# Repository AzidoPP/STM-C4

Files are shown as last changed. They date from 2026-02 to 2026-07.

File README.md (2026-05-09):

# STM-C4
A CS2 C4 model based on STM32.





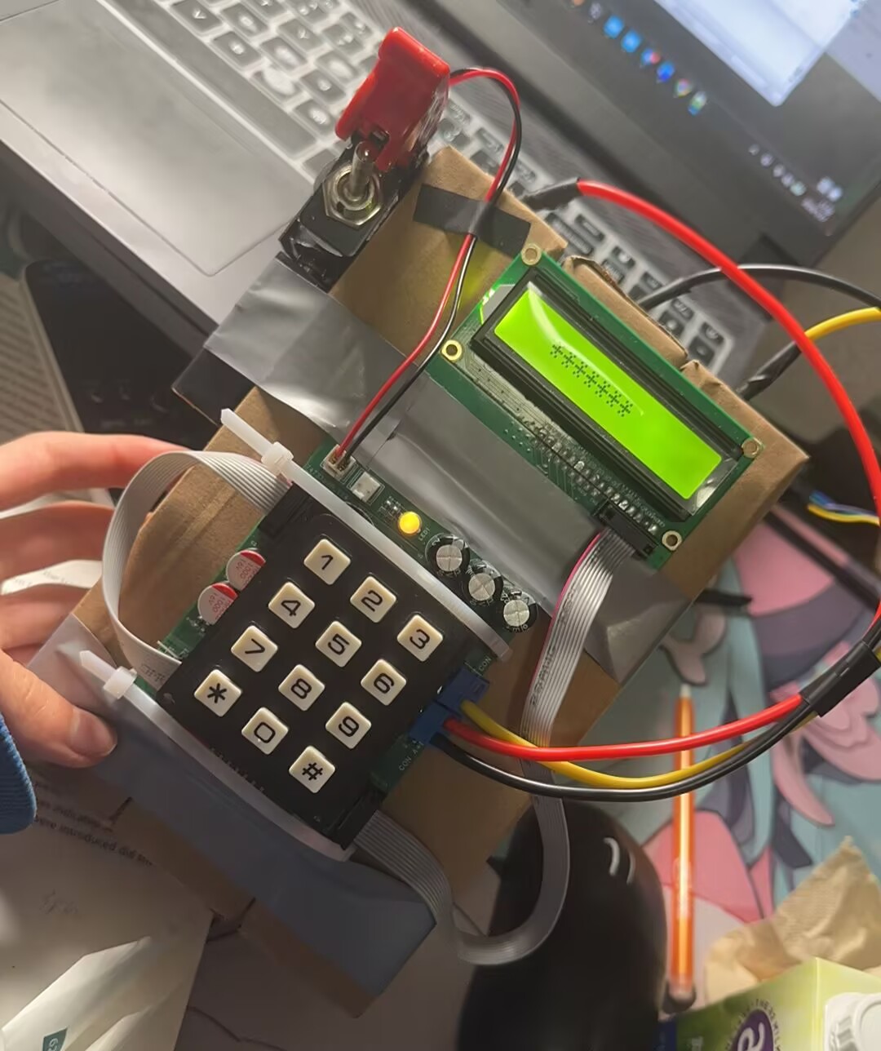
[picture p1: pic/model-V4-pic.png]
model-v4-pic


## 简介
- 基于 STM32F103C8T6 的 CS2 C4 外观模型，主要用于学习、展示与收藏。
- 开发环境：Keil5 + ST-Link，外部 8 MHz 晶振。
- 快速开始: **[Ver4.0](Ver4.0)**。
- 配置修改请参考：[`Ver4.0/CONFIG.md`](Ver4.0/CONFIG.md)

## 特别感谢
- 感谢 Bilibili 博主「下界石嘤」提供 3D 打印模型：[https://space.bilibili.com/318570767](https://space.bilibili.com/318570767)

[English](#english)

## 免责声明
本项目为外观复刻模型，不具备任何真实功能或危险性。
任何改装、滥用或非法使用均与原作者无关，原作者不承担由此产生的责任。

## English
- A CS2 C4 appearance model based on STM32F103C8T6, for learning, demos, and collection.
- Tooling: Keil5 + ST-Link with an external 8 MHz HSE.
- Quick start: **[Ver4.0](Ver4.0)**
- For configuration edits, see [`Ver4.0/CONFIG.md`](Ver4.0/CONFIG.md).

## Special Thanks
- Thanks to Bilibili creator “下界石嘤” for providing the 3D printable models: [https://space.bilibili.com/318570767](https://space.bilibili.com/318570767)

## Disclaimer
This project is a replica appearance model and has no real functionality or hazardous capability.
Any modification, misuse, or illegal use is not associated with the original creator, who assumes no responsibility for any consequences.

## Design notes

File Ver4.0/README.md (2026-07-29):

# STM-C4 Ver4.0

<div align="right">
  <strong>English</strong> | <a href="README_zh.md">简体中文</a>
</div>






An STM32F103C8T6-based CS2 C4 appearance model (V4.0). About 95% visual accuracy. Compared to the previous version, this revision optimizes the LCD ribbon width, uses multi-color LEDs, adds a passive buzzer for distinct tones, and introduces an external defuser option. The hardware integrates the power circuit and uses a PCB-mounted controller instead of a full dev board. On the software side, the countdown uses a more accurate formula, smoother animations, and more configurable options with a more authentic LCD effect.

GitHub repo (firmware/docs): https://github.com/AzidoPP/STM-C4  
OSHWHUB hardware page: https://oshwhub.com/azidopp/CS2-C4

### Real Picture



### Quick Start

1. PCB fabrication
   - Main board Gerber: [PCB_Gerber/Gerber_C4_MainBoardV4.1.zip](PCB_Gerber/Gerber_C4_MainBoardV4.1.zip)
   - LCD adapter Gerber: [PCB_Gerber/Gerber_LCD1601_AdapterBoardV4.0.zip](PCB_Gerber/Gerber_LCD1601_AdapterBoardV4.0.zip)
   - EasyEDA original project files (this repo): [EasyEDA_proj](EasyEDA_proj/)
   - See OSHWHUB for the full hardware [project files](https://oshwhub.com/azidopp/CS2-C4)
2. BOM purchase
   - BOM file: [BOM/BOM.xlsx](BOM/BOM.xlsx)
   - 9V alkaline batteries are recommended for more stable current output
3. Soldering & assembly
   - LCD1601 adapter soldering example:
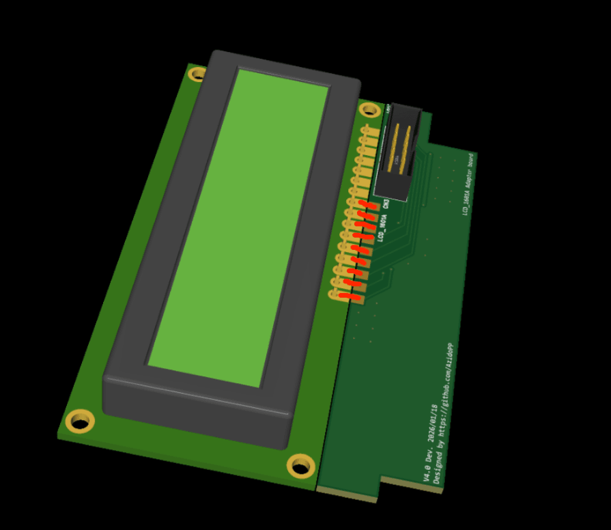
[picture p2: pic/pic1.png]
LCD1601 adapter pic1
     
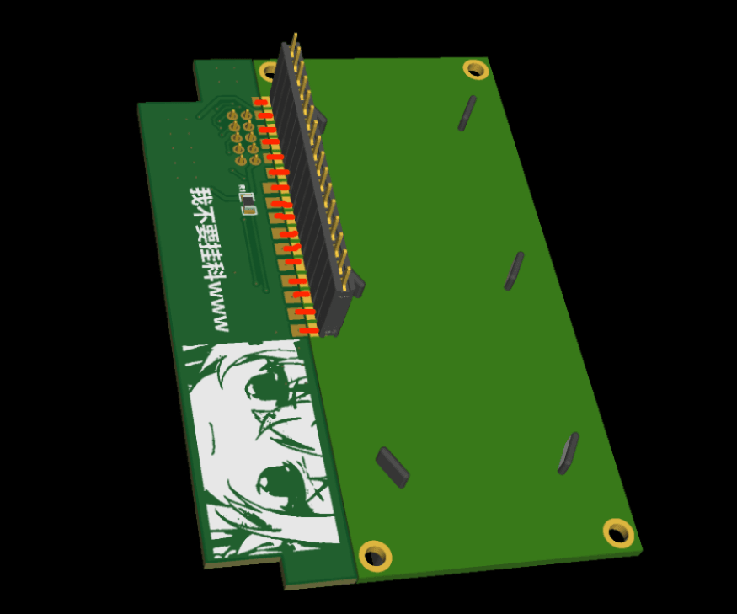
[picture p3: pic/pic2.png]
LCD1601 adapter pic2
     
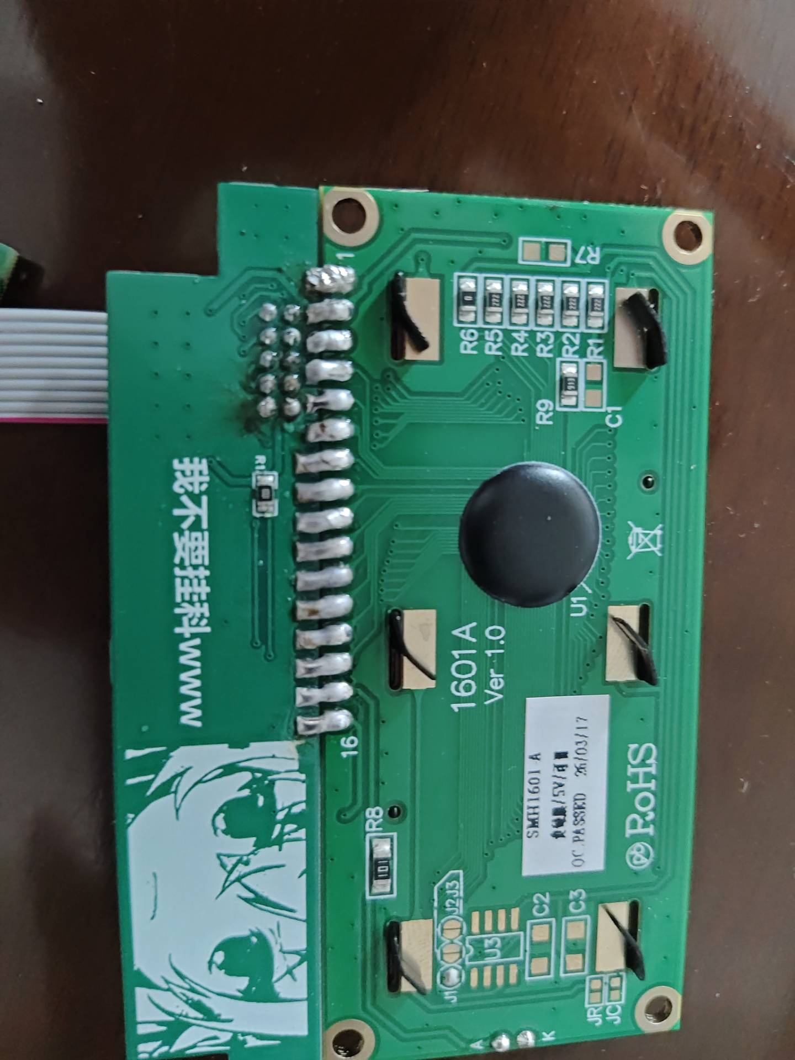
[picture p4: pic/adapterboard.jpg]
LCD1601 adapter pic3
     
   - 3D printed shell/fillers (optional): see [3DP_Models](3DP_Models/)
   - Fully assembled board:
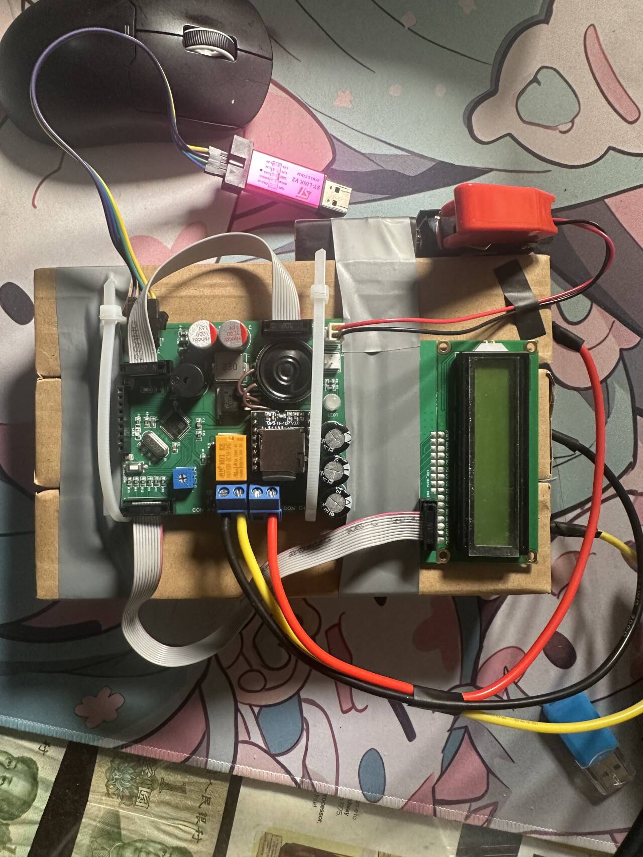
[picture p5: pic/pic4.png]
Full assambled board
     
4. Flash firmware
   - Keil project: [Keil_proj/c4](Keil_proj/c4/)
   - ST-Link V2 header location:
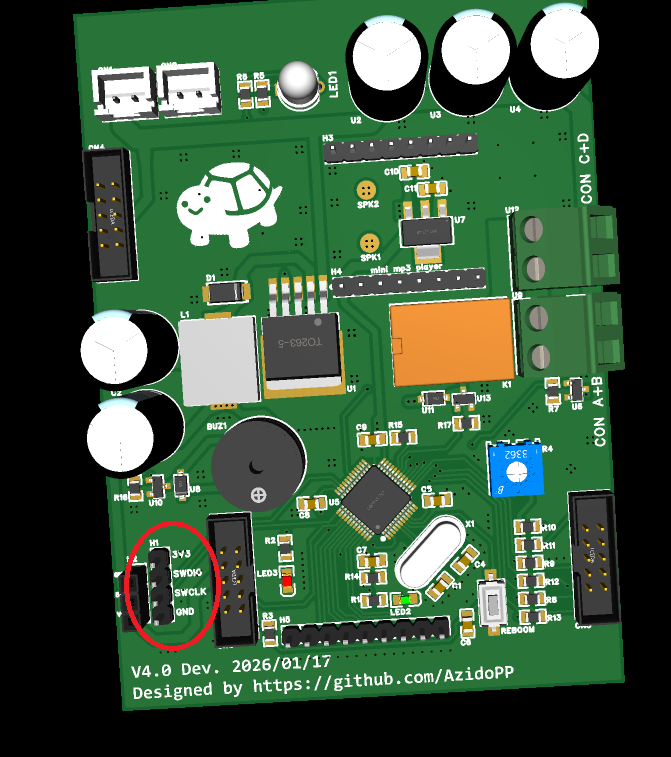
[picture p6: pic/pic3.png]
ST-Link header pic3
     
   - Pin order: 3.3V / SWDIO / SWCLK / GND
   - After flashing the firmware, if the LCD1601 shows no text, rotate the potentiometer in either direction to adjust the display contrast until the text is clear.
     potentiometer
5. MP3 audio (optional)
   - Copy [TFCard_Files/](TFCard_Files/) contents to the TF card root
   - Details: [TFCard_Files](TFCard_Files/)
6. Configuration and tuning
   - User guide: [`CONFIG.md`](CONFIG.md)
   - Default configuration source: [`config.h`](Keil_proj/c4/user/config.h)
   - Supports single-item configuration update without reflashing (hold `#` during power-on)
   - Added digital countdown toggle: `CONFIG_DIGITAL_COUNTDOWN_ENABLE`

### Basic Gameplay

- Startup uses buzzer only (no MP3), while LED breathes in yellow.
- Enter any 7-digit code as the “plant” password.
- After entry, the countdown starts (default 40s, configurable); the LED and buzzer become more urgent.
- During the countdown, there are three defuse methods:
  - Password defuse: enter the same password again to defuse successfully.
  - Manual defuse: long press `#` to start; succeed after 10 seconds.
  - External defuser: when the external defuse input is active, hold for 5 seconds to succeed.
- Defuse-success sequence: defuse-success cue (separate toggle) -> (optional) CT music box -> (optional) CT win announcement.
- Explosion sequence:
  - With T music box enabled: play integrated explosion+music-box track -> (optional) T win announcement.
  - Without T music box: play pure explosion track -> (optional) T win announcement.

### Configuration

- User-facing configuration guide: [`CONFIG.md`](CONFIG.md)
- Technical notes: [`V4说明.md`](V4说明.md)
- Default configuration source: [`config.h`](Keil_proj/c4/user/config.h)

### Detailed Docs

For deeper details and theory, see the Chinese technical document: [V4说明.md](V4说明.md)

### Disclaimer

This project is a visual/electronic replica and does not have any real functionality or danger.  
Any modification, misuse, or illegal use is not associated with the author, and the author assumes no liability.

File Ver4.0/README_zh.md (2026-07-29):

# STM-C4 Ver4.0

<div align="right">
  <a href="README.md">English</a> | <strong>简体中文</strong>
</div>






基于 STM32F103C8T6 的 CS2 C4 光电模型，第 4 版。还原度约 95%，相较于先前版本，优化了显示屏排线宽度，使用多色 LED，使用无源蜂鸣器（可以发出不同音调），添加了“拆弹器”支持。硬件方面使用了集成的电源电路，以及集成在 PCB 上的控制器取代原先的整个开发板。软件方面改进：倒计时使用了更还原的公式，修改了更好的动画，添加了更多可配置选项，使用了更还原的显示屏动画。

GitHub 仓库（程序/文档）：https://github.com/AzidoPP/STM-C4  
OSHWHUB 硬件开源地址：https://oshwhub.com/azidopp/CS2-C4

### 实物图



### 快速开始

1. PCB 打样
   - 主板 Gerber：[PCB_Gerber/Gerber_C4_MainBoardV4.1.zip](PCB_Gerber/Gerber_C4_MainBoardV4.1.zip)
   - LCD 转接板 Gerber：[PCB_Gerber/Gerber_LCD1601_AdapterBoardV4.0.zip](PCB_Gerber/Gerber_LCD1601_AdapterBoardV4.0.zip)
   - 立创 EDA 原始工程文件（本仓库）：[EasyEDA_proj](EasyEDA_proj/)
   - 详细工程请参考 OSHWHUB 开源硬件平台[工程](https://oshwhub.com/azidopp/CS2-C4)
2. 采购 BOM
   - BOM 文件：[BOM/BOM.xlsx](BOM/BOM.xlsx)
   - 9V 电池建议使用碱性电池（输出电流更稳定）
3. 焊接与装配
   - LCD1601 转接板焊接示例：
     LCD1601 adapter pic1
     LCD1601 adapter pic2
     LCD1601 adapter pic3
   - 3D 打印外壳/填充件（可选）：见 [3DP_Models](3DP_Models/)
   - 完整组装：
     Full assambled board
4. 烧录固件
   - Keil 工程：[Keil_proj/c4](Keil_proj/c4/)
   - ST-Link V2 接口位置：
     ST-Link header pic3
   - 引脚顺序：3.3V / SWDIO / SWCLK / GND
   - 烧录固件后，如果 LCD1601 显示屏不显示，请旋转电位器调整屏幕对比度，左右旋转，直到出现清晰的文字。
     potentiometer
5. MP3 音效（可选）
   - 将 [TFCard_Files/](TFCard_Files/) 内容复制到 TF 卡根目录
   - 详细说明见：[TFCard_Files](TFCard_Files/)
6. 配置与修改
   - 用户配置说明：[`CONFIG.md`](CONFIG.md)
   - 默认配置定义文件：[`Keil_proj/c4/user/config.h`](Keil_proj/c4/user/config.h)
   - 可在不重新烧录的情况下修改单个配置（上电时按住 `#` 进入配置模式）
   - 新增倒计时数字显示开关：`CONFIG_DIGITAL_COUNTDOWN_ENABLE`

### 基础玩法

- 上电阶段仅蜂鸣器提示（不播放 MP3），LED 为黄色呼吸灯模式。
- 输入任意 7 位密码，作为“下包密码”。
- 输入完成后进入倒计时（默认 40 秒，可配置），期间 LED 和蜂鸣器会逐渐急迫。
- 倒计时期间有三种拆弹方式：
  - 输入拆弹：再次输入与下包一致的密码即可拆弹成功。
  - 手动拆弹：长按 `#` 开始拆弹，持续 10 秒后成功。
  - 外部拆弹器：外部拆弹输入有效时开始拆弹，持续 5 秒即成功。
- 拆弹成功播放序列：拆弹成功音（可单独开关）->（可选）CT 音乐盒 ->（可选）CT 胜利播报。
- 倒计时结束未拆弹播放序列：
  - 启用 T 音乐盒：播放“爆炸+T 音乐盒”整合音频 ->（可选）T 胜利播报。
  - 未启用 T 音乐盒：播放纯爆炸音效 ->（可选）T 胜利播报。

### 配置

- 用户配置指南（含编号与操作步骤）：[`CONFIG.md`](CONFIG.md)
- 默认配置定义文件：[`Keil_proj/c4/user/config.h`](Keil_proj/c4/user/config.h)
- 技术说明：[`V4说明.md`](V4说明.md)

### 详细说明

更多细节与原理说明请查看：[V4说明.md](V4说明.md)

### 免责声明

本项目为外观光电复刻模型，不具备任何真实功能或危险性。  
任何改装、滥用或非法使用与原作者无关，原作者不承担责任。

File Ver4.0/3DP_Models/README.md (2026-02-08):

# 3D 打印说明

## 中文
- `C4_filler` 为填充件，请务必打印。
- 单个填充件尺寸约 190 x 40 x 43 mm（长 x 宽 x 高），以模型文件为准。
- 整体外壳尺寸约 190 x 123 mm（长 x 宽），以模型文件为准。
- 建议填充率 7%~15%，普通材料即可，性价比高。
- 没有打印机可找本地 3D 打印代工，或联系模型提供者 UP 主获取打印件（见下方链接）。
- 不建议选择超低价平台，容易踩坑。
- 总开关外壳文件：`switch_shell`，推荐黑色。

模型来源：
- Bilibili 博主「下界石嘤」提供
- 链接：[https://space.bilibili.com/318570767](https://space.bilibili.com/318570767)

---

## English
- `C4_filler` is the filler part and must be printed.
- Filler size is about 190 x 40 x 43 mm (L x W x H). Refer to the model files for exact dimensions.
- Overall shell size is about 190 x 123 mm (L x W). Refer to the model files for exact dimensions.
- Recommended infill: 7%–15%. Standard materials are fine and cost-effective.
- If you don't have a printer, use a local 3D printing service or contact the model provider (see the link below) for printed parts.
- Avoid ultra-cheap platforms; the quality and pricing are often unreliable.
- Main switch shell file: `switch_shell`, black color recommended.

Model credit:
- Provided by Bilibili creator “下界石嘤”
- Link: [https://space.bilibili.com/318570767](https://space.bilibili.com/318570767)

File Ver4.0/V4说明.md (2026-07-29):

# STM-C4 Ver4.0 说明

主控 STM32F103C8T6，外部 8MHz 高速晶振，使用 Keil5 + ST-Link。

A CSGO game C4 bomb model based on STM32.

## 1. LCD1601A
- 默认倒装安装（`CONFIG_LCD_NORMAL_MOUNT = 0`），正装可设为 `1`。
- 倒装时显示从右往左，字符需整体旋转 180 度；正装时按正常方向显示。
  - 例如用户看到左对齐的 `ABCDEF`，倒装实际需要显示右对齐的 `FEDCBA` 并旋转字符。
- 字符集：实际只需要 `0123456789*`（驱动内置 CGRAM 字库）。
- 采用 4 线模式。

引脚定义（硬件连接）：
- RS: PB12
- EN: PB14
- D4 ~ D7: PA4 ~ PA7
- 背光：PA3（高电平点亮，推挽，PWM 控制，亮度 `CONFIG_LCD_BACKLIGHT_PCT`）

电平/驱动：
- LCD1601A 使用 5V 电平，外部上拉到 5V。
- 信号脚使用开漏输出（OD）。

实现要点（简化说明）：
- 初始化流程与 HD44780 类似：上电延时、写入 0x03/0x02、功能设置、清屏、显示开等。
- 通过自定义 CGRAM 字库加载字符；显示方向与列映射由驱动根据 `CONFIG_LCD_NORMAL_MOUNT` 处理。
- 字体按 7x5 顶部对齐显示（底部 1 行留空），避免底部贴边。
- 参考实现见：`Ver4.0/Keil_proj/c4/hardware/1601a.c`

## 2. 矩阵键盘
- 引脚：PB15 PB4 PB5 PB6 PB7 PB8 PB9
- 排列：

```
        PB5     PB15    PB7
PB4     [1]     [2]     [3]
PB9     [4]     [5]     [6]
PB8     [7]     [8]     [9]
PB6     [*]     [0]     [#]
```

## 3. 蜂鸣器
- 无源蜂鸣器（含驱动电路，MOS 管，栅极 10k 下拉）。
- 栅极连接 PB0。
- PB0 输出 PWM 波驱动。
- 原版CS2中，A区下包后倒计时音频为4250Hz，B区下包倒计时为3600Hz

## 4. LED
- PC13：系统指示 LED（一般不用，仅调试，推挽高电平点亮）。
- 用户双色 LED（推挽高电平点亮）：
  - PA2 红
  - PA1 绿
- 黄色由红绿同时点亮并用 PWM 调节比例，比例由 `CONFIG_LED_YELLOW_RED_PCT` 控制。
  - 例如 `CONFIG_LED_YELLOW_RED_PCT = 70` 表示红色约 70%、绿色 100%。

## 5. 继电器
- 已包含 MOS + 续流驱动。
- PB1 高电平：继电器吸合。
- 倒计时结束后“引爆”吸合继电器
- 端口`C`为继电器常开脚，端口`D`为继电器常闭脚。吸合后`C`脚成为GND，可以与`A`脚（VCC）产生9V电压。

## 6. MP3 模块
- PA9 串口（USART1 TX），用于播放 C4 模型音效/音乐盒。
- MP3 命令封装参考：`Ver4.0/Keil_proj/c4/hardware/Serial.c` 与 `mp3.c`。
- 主逻辑采用 `MP3Sequence` 状态机（`main.c`），所有流程音频统一由状态机调度。
- 播放方式：按文件名播放，音频统一放在 TF 卡根目录 `MP3/` 文件夹。
- 固定播报编号：
  - 下包成功：`CONFIG_MP3_TRACK_ARM_SUCCESS`（默认 0101）
  - 纯爆炸：`CONFIG_MP3_TRACK_EXPLOSION`（默认 0102）
  - 拆弹成功：`CONFIG_MP3_TRACK_DEFUSE_SUCCESS`（默认 0103）
  - CT 胜利播报：`CONFIG_MP3_TRACK_CTWIN`（默认 0104）
  - T 胜利播报：`CONFIG_MP3_TRACK_TERWIN`（默认 0105）
- 音乐盒编号由配置控制：`CONFIG_MP3_CT_WIN_MUSICBOX_TRACK` / `CONFIG_MP3_T_WIN_MUSICBOX_TRACK`。

详细映射见：`TFCard_Files/README.md`

## 7. 外部“拆弹器”
- PB3 上拉输入，低电平有效。
- PB3 外部持续下拉达到 `CONFIG_EXTERNAL_DEFUSE_MS` 即判定拆弹成功（默认 5000ms）。

## 流程（完整）
1. LED 黄色呼吸灯模式（`CONFIG_LED_BREATH_PERIOD_MS`）。
2. 上电音频：仅蜂鸣器（`CONFIG_STARTUP_BEEP_ENABLE` / `CONFIG_STARTUP_BEEP_ON_MS` / `CONFIG_STARTUP_BEEP_GAP_MS`），不播放 MP3。
3. 倒计时蜂鸣器频率：`CONFIG_BUZZER_COUNTDOWN_FREQ_HZ`。
4. 等待输入密码（长度 `CONFIG_PASSWORD_LEN`）。未输入时显示全 `+`；输入第一位后，未填位改为 `-`，数字从右向左累积。输入完成后延迟 `CONFIG_ARM_DELAY_MS` 再进入倒计时，避免误触。
5. 记录该密码（输入期间 LED 仍为呼吸灯）。
6. 进入倒计时（总时长 `CONFIG_COUNTDOWN_MS`）：
   - 蜂鸣节奏由 `CONFIG_BEEP_LEN_MS` 与 `CONFIG_BEEP_INTERVAL_*` 控制
   - 每次蜂鸣时 LED 红色，非蜂鸣时 LED 熄灭

## 倒计时蜂鸣模式
原 CS:GO C4 蜂鸣公式如下（BPS = Beeps Per Second）：

```
f(t) = 1.05 · exp(0.0054t + 0.000871t²)
```
- t：时间（秒），0 ≤ t ≤ 45

更通用的比例形式：
```
g(p) = 1.049 · exp(0.244p + 1.764p²)
```
- p：已过去时间比例，0.0 ≤ p ≤ 1.0

蜂鸣长度固定为 125ms。

频率：
```
freq = MAX(0.1 + 0.9 * fComplete, 0.15)
```
- fComplete 为剩余时间比例（40/40 到 0/40）
- 下包后设置下一次蜂鸣时间：`gpGlobals->curtime + 1.0`

倒计时时显示 `+++` 往返滚动；默认关闭数字倒计时，此时动画覆盖整行。开启数字倒计时后，`+++` 仅在左半区滚动，右半区显示 `mm:ss`。

注意：LCD1601A 是倒装的，所以符号位置与显示方向需整体翻转 180°。

## 倒计时拆弹（3 种方式，且必须非阻塞）
> 拆弹失败或进行中都不应影响倒计时精度。旧版本因键盘扫描 + 倒计时循环阻塞，长按按键会导致消抖延时叠加、倒计时不准。V4.0 采用时间基准 + 状态机避免此问题。

1. **输入密码拆弹**：输入与下包相同密码即成功（`CONFIG_DEFUSE_ENABLE_PASSWORD`）。
2. **长按 # 手动拆弹**：长按超过 `CONFIG_LONG_PRESS_MS` 后开始拆弹，持续 `CONFIG_MANUAL_DEFUSE_MS` 即成功（`CONFIG_DEFUSE_ENABLE_MANUAL`）。
   - 过程显示：右端数字按 `CONFIG_DEFUSE_CYCLE_STEPS` 滚动，已确认的正确密码逐位向左累积；其余位以 `+` 和 `-` 交替闪烁。
3. **外部拆弹器拆弹**：PB3 触发后开始拆弹，持续 `CONFIG_EXTERNAL_DEFUSE_MS` 即成功（`CONFIG_DEFUSE_ENABLE_EXTERNAL`）。

拆弹成功后，LCD 按 `+++++++` → `-------` → 正确密码循环显示，每帧间隔由 `CONFIG_DEFUSE_BLINK_MS` 控制。

拆弹成功会进入 DEFUSE 音频序列：
- 若启用 `CONFIG_MP3_DEFUSE_STAGE_ENABLE`：
  - 若启用 `CONFIG_MP3_DEFUSE_SUCCESS_ENABLE`，播放 `CONFIG_MP3_TRACK_DEFUSE_SUCCESS` 并等待 `CONFIG_MP3_DEFUSE_SUCCESS_WAIT_MS`
  - 若启用 `CONFIG_MP3_CT_WIN_MUSICBOX_ENABLE`，播放 `CONFIG_MP3_CT_WIN_MUSICBOX_TRACK` 并等待 `CONFIG_MP3_CT_MUSICBOX_WAIT_MS`
  - 若启用 `CONFIG_MP3_CTWIN_ENABLE`，播放 `CONFIG_MP3_TRACK_CTWIN`

## 爆炸行为
- 倒计时结束未拆弹：继电器吸合。
- 播放 EXPLOSION 序列（按配置可启停各阶段）：
  - 若启用 `CONFIG_MP3_EXPLODED_STAGE_ENABLE` 且启用 `CONFIG_MP3_EXPLOSION_ENABLE`：
    - 启用 `CONFIG_MP3_T_WIN_MUSICBOX_ENABLE`：播放 T 音乐盒并等待 `CONFIG_MP3_T_MUSICBOX_WAIT_MS`
    - 未启用 T 音乐盒：播放纯爆炸音效并等待 `CONFIG_MP3_EXPLOSION_ONLY_WAIT_MS`
  - 若启用 `CONFIG_MP3_TERWIN_ENABLE`，播放 `CONFIG_MP3_TRACK_TERWIN`
- LED 输出 100% 黄色（LED 与音乐盒同时）。

## 软件架构（文件职责）
- `Ver4.0/Keil_proj/c4/user/main.c`
  - 应用状态机与主循环（Idle/Countdown/Success/Exploded）
  - 倒计时逻辑、拆弹流程、输入处理
- `Ver4.0/Keil_proj/c4/sys/Systick.c`
  - 1ms 时间基准（TIM4 中断）
- `Ver4.0/Keil_proj/c4/user/stm32f10x_it.c`
  - TIM4 中断处理，驱动时间基准
- `Ver4.0/Keil_proj/c4/hardware/MatrixKey.c`
  - 矩阵键盘扫描与消抖
- `Ver4.0/Keil_proj/c4/hardware/1601a.c`
  - LCD1601A 驱动（倒装/正装显示、CGRAM 字库、背光 PWM）
- `Ver4.0/Keil_proj/c4/hardware/LED.c`
  - 红/绿 LED PWM、黄色配比、继电器控制
  - 蜂鸣器 PWM 频率与占空比控制
- `Ver4.0/Keil_proj/c4/hardware/Serial.c`
  - USART1 发送封装（供 MP3 模块使用）
- `Ver4.0/Keil_proj/c4/hardware/mp3.c`
  - MP3 指令封装
- `Ver4.0/Keil_proj/c4/sys/Delay.c`
  - 短时硬件延时（LCD 时序/少量效果）
- `Ver4.0/Keil_proj/c4/user/config.h`
  - 功能开关与参数配置
- `Ver4.0/Keil_proj/c4/user/config_range.h`
  - 配置范围检查

## 配置入口
配置集中在 `Ver4.0/Keil_proj/c4/user/config.h`，用户说明在 `Ver4.0/config.md`。

新增运行时配置管理：
- `Ver4.0/Keil_proj/c4/user/config_manager.c`
- `Ver4.0/Keil_proj/c4/user/config_manager.h`

运行时配置机制要点：
- 程序启动时读取配置记录；若记录无效/版本不匹配/配置项数量不匹配，则回退到固件内默认值。
- 配置结构附带 magic / version / count / checksum，用于兼容新增配置项。
- 重新烧录后若配置结构变化，旧记录不会被继续使用。
- Keil + ST-Link 下载通常会擦除目标程序相关区域；是否整片擦除取决于下载配置，不保证每次整片擦除。

配置模式流程（上电按住 `#`）：
- 进入条件：上电/复位后的极短检测窗口内检测到已按住 `#`，并继续按住一小段时间后进入。
- 操作：输入配置编号 -> 输入新值 -> 保存确认。
- 特殊输入码：`090405`（固定 6 位）进入恢复默认确认流程。
- 保存或恢复成功后，停留提示并等待用户 `RESET`。

显示约束处理：
- LCD 仅 16 字符，配置模式统一使用短提示（如 `ID:` / `VAL:` / `SAVE?` / `RESET`）。
- 避免提示过长导致可读性下降。

倒计时显示新增：
- 新增 `CONFIG_DIGITAL_COUNTDOWN_ENABLE`。
- 开启后：左侧保持滚动动画，右侧 8 字符区域显示 `mm:ss`（前置 2 个空格）。
- 进入拆弹动画时自动隐藏数字倒计时，仅显示拆弹动画。

常用配置（宏）：
- 密码与上电：`CONFIG_PASSWORD_LEN` / `CONFIG_PASSWORD_COL` / `CONFIG_ARM_DELAY_MS` / `CONFIG_ARM_PRESET_ENABLE` / `CONFIG_ARM_PRESET_PASSWORD`
- 倒计时与滚动：`CONFIG_COUNTDOWN_MS` / `CONFIG_SCROLL_INTERVAL_MS` / `CONFIG_SCROLL_PATTERN_LEN`（预留，当前实现固定三个加号）
- 蜂鸣器节奏：`CONFIG_BEEP_LEN_MS` / `CONFIG_BEEP_INTERVAL_BASE_MS` / `CONFIG_BEEP_INTERVAL_SCALE_MS` / `CONFIG_BEEP_INTERVAL_MIN_MS` / `CONFIG_BEEP_INITIAL_MS`
- 蜂鸣器频率：`CONFIG_BUZZER_STARTUP_FREQ_HZ` / `CONFIG_BUZZER_COUNTDOWN_FREQ_HZ` / `CONFIG_BUZZER_DUTY_PCT`
- 拆弹设置：`CONFIG_DEFUSE_ENABLE_PASSWORD` / `CONFIG_DEFUSE_ENABLE_MANUAL` / `CONFIG_DEFUSE_ENABLE_EXTERNAL`
- 拆弹时间与过程：`CONFIG_LONG_PRESS_MS` / `CONFIG_MANUAL_DEFUSE_MS` / `CONFIG_EXTERNAL_DEFUSE_MS` / `CONFIG_DEFUSE_CYCLE_STEPS` / `CONFIG_DEFUSE_DISPLAY_HOLD_MS`
- 拆弹成功显示：`CONFIG_DEFUSE_BLINK_MS`（当前生效）/ `CONFIG_DEFUSE_FLASH_TOGGLE_MS` / `CONFIG_DEFUSE_FLASH_TOGGLES`（预留）
- LCD/LED：`CONFIG_LCD_COLS` / `CONFIG_LCD_BACKLIGHT_PCT` / `CONFIG_LCD_NORMAL_MOUNT` / `CONFIG_LED_PWM_MAX` / `CONFIG_LED_BREATH_PERIOD_MS` / `CONFIG_LED_YELLOW_RED_PCT`
- MP3：
  - 基础：`CONFIG_MP3_VOLUME` / `CONFIG_MP3_ARM_SUCCESS_ENABLE`
  - 固定播报号：`CONFIG_MP3_TRACK_ARM_SUCCESS` / `CONFIG_MP3_TRACK_EXPLOSION` / `CONFIG_MP3_TRACK_DEFUSE_SUCCESS` / `CONFIG_MP3_TRACK_CTWIN` / `CONFIG_MP3_TRACK_TERWIN`
  - 阶段总开关：`CONFIG_MP3_DEFUSE_STAGE_ENABLE` / `CONFIG_MP3_EXPLODED_STAGE_ENABLE`
  - 子开关：`CONFIG_MP3_DEFUSE_SUCCESS_ENABLE` / `CONFIG_MP3_EXPLOSION_ENABLE` / `CONFIG_MP3_CT_WIN_MUSICBOX_ENABLE` / `CONFIG_MP3_T_WIN_MUSICBOX_ENABLE` / `CONFIG_MP3_CTWIN_ENABLE` / `CONFIG_MP3_TERWIN_ENABLE`
  - 音乐盒编号：`CONFIG_MP3_CT_WIN_MUSICBOX_TRACK` / `CONFIG_MP3_T_WIN_MUSICBOX_TRACK`
  - 等待时长：`CONFIG_MP3_DEFUSE_SUCCESS_WAIT_MS` / `CONFIG_MP3_CT_MUSICBOX_WAIT_MS` / `CONFIG_MP3_T_MUSICBOX_WAIT_MS` / `CONFIG_MP3_EXPLOSION_ONLY_WAIT_MS`

## 工程与编译
Keil 工程文件：`Ver4.0/Keil_proj/c4/Project.uvprojx`

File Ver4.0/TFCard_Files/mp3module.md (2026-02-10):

Copy your mp3 into you micro SD card

NOTE: The order you copy the mp3 into micro SD card will affect the order mp3 played , which means play(1) function will play the first mp3 copied into micro SD card.

For Mac User

NOTE: If you are using Mac OS X to copy the mp3, the file system will automatically add hidden files like: ".\_0001.mp3" for index, which this module will handle as valid mp3 files. It is really annoying. So you can run following command in terminal to eliminate those files.

dot\_clean /Volumes/<SDVolumeName>

Please replace the to the volume name of your SD card.

Sample Code

We've created an Arduino library for DFPlayer Mini to simplify the method for you to make it work.

Connect the hardware as the picture above shown and play with the sample code.

You can download the latest library here: DFRobotDFPlayerMini.

Sample code "GetStarted", switching to next song every 3 seconds

/\*\*\*\*\*\*\*\*\*\*\*\*\*\*\*\*\*\*\*\*\*\*\*\*\*\*\*\*\*\*\*\*\*\*\*\*\*\*\*\*\*\*\*\*\*\*\*\*\*\*\*

DFPlayer - A Mini MP3 Player For Arduino

&nbsp;<https://www.dfrobot.com/product-1121.html>

&nbsp;

&nbsp;\*\*\*\*\*\*\*\*\*\*\*\*\*\*\*\*\*\*\*\*\*\*\*\*\*\*\*\*\*\*\*\*\*\*\*\*\*\*\*\*\*\*\*\*\*\*\*\*\*\*\*

&nbsp;This example shows the basic function of library for DFPlayer.

&nbsp;

&nbsp;Created 2016-12-07

&nbsp;By \[Angelo qiao](Angelo.qiao@dfrobot.com)

&nbsp;

&nbsp;GNU Lesser General Public License.

&nbsp;See <http://www.gnu.org/licenses/> for details.

&nbsp;All above must be included in any redistribution

&nbsp;\*\*\*\*\*\*\*\*\*\*\*\*\*\*\*\*\*\*\*\*\*\*\*\*\*\*\*\*\*\*\*\*\*\*\*\*\*\*\*\*\*\*\*\*\*\*\*\*\*\*\*\*/

/\*\*\*\*\*\*\*\*\*\*\*Notice and Trouble shooting\*\*\*\*\*\*\*\*\*\*\*\*\*\*\*

&nbsp;1.Connection and Diagram can be found here

&nbsp;<https://www.dfrobot.com/wiki/index.php/DFPlayer\_Mini\_SKU:DFR0299#Connection\_Diagram>

&nbsp;2.This code is tested on Arduino Uno, Leonardo, Mega boards.

&nbsp;\*\*\*\*\*\*\*\*\*\*\*\*\*\*\*\*\*\*\*\*\*\*\*\*\*\*\*\*\*\*\*\*\*\*\*\*\*\*\*\*\*\*\*\*\*\*\*\*\*\*\*\*/

\#include "Arduino.h"

\#include "DFRobotDFPlayerMini.h"

\#if (defined(ARDUINO\_AVR\_UNO) || defined(ESP8266))   // Using a soft serial port

\#include <SoftwareSerial.h>

SoftwareSerial softSerial(/\*rx =\*/10, /\*tx =\*/11);

\#define FPSerial softSerial

\#else

\#define FPSerial Serial1

\#endif

DFRobotDFPlayerMini myDFPlayer;

void printDetail(uint8\_t type, int value);

void setup()

{

\#if (defined ESP32)

&nbsp; FPSerial.begin(9600, SERIAL\_8N1, /\*rx =\*/D3, /\*tx =\*/D2);

\#else

&nbsp; FPSerial.begin(9600);

\#endif

&nbsp; Serial.begin(115200);

&nbsp; Serial.println();

&nbsp; Serial.println(F("DFRobot DFPlayer Mini Demo"));

&nbsp; Serial.println(F("Initializing DFPlayer ... (May take 3~5 seconds)"));

&nbsp; 

&nbsp; if (!myDFPlayer.begin(FPSerial, /\*isACK = \*/true, /\*doReset = \*/true)) {  //Use serial to communicate with mp3.

&nbsp;   Serial.println(F("Unable to begin:"));

&nbsp;   Serial.println(F("1.Please recheck the connection!"));

&nbsp;   Serial.println(F("2.Please insert the SD card!"));

&nbsp;   while(true){

&nbsp;     delay(0); // Code to compatible with ESP8266 watch dog.

&nbsp;   }

&nbsp; }

&nbsp; Serial.println(F("DFPlayer Mini online."));

&nbsp; 

&nbsp; myDFPlayer.volume(10);  //Set volume value. From 0 to 30

&nbsp; myDFPlayer.play(1);  //Play the first mp3

}

void loop()

{

&nbsp; static unsigned long timer = millis();

&nbsp; 

&nbsp; if (millis() - timer > 3000) {

&nbsp;   timer = millis();

&nbsp;   myDFPlayer.next();  //Play next mp3 every 3 second.

&nbsp; }

&nbsp; 

&nbsp; if (myDFPlayer.available()) {

&nbsp;   printDetail(myDFPlayer.readType(), myDFPlayer.read()); //Print the detail message from DFPlayer to handle different errors and states.

&nbsp; }

}

void printDetail(uint8\_t type, int value){

&nbsp; switch (type) {

&nbsp;   case TimeOut:

&nbsp;     Serial.println(F("Time Out!"));

&nbsp;     break;

&nbsp;   case WrongStack:

&nbsp;     Serial.println(F("Stack Wrong!"));

&nbsp;     break;

&nbsp;   case DFPlayerCardInserted:

&nbsp;     Serial.println(F("Card Inserted!"));

&nbsp;     break;

&nbsp;   case DFPlayerCardRemoved:

&nbsp;     Serial.println(F("Card Removed!"));

&nbsp;     break;

&nbsp;   case DFPlayerCardOnline:

&nbsp;     Serial.println(F("Card Online!"));

&nbsp;     break;

&nbsp;   case DFPlayerUSBInserted:

&nbsp;     Serial.println("USB Inserted!");

&nbsp;     break;

&nbsp;   case DFPlayerUSBRemoved:

&nbsp;     Serial.println("USB Removed!");

&nbsp;     break;

&nbsp;   case DFPlayerPlayFinished:

&nbsp;     Serial.print(F("Number:"));

&nbsp;     Serial.print(value);

&nbsp;     Serial.println(F(" Play Finished!"));

&nbsp;     break;

&nbsp;   case DFPlayerError:

&nbsp;     Serial.print(F("DFPlayerError:"));

&nbsp;     switch (value) {

&nbsp;       case Busy:

&nbsp;         Serial.println(F("Card not found"));

&nbsp;         break;

&nbsp;       case Sleeping:

&nbsp;         Serial.println(F("Sleeping"));

&nbsp;         break;

&nbsp;       case SerialWrongStack:

&nbsp;         Serial.println(F("Get Wrong Stack"));

&nbsp;         break;

&nbsp;       case CheckSumNotMatch:

&nbsp;         Serial.println(F("Check Sum Not Match"));

&nbsp;         break;

&nbsp;       case FileIndexOut:

&nbsp;         Serial.println(F("File Index Out of Bound"));

&nbsp;         break;

&nbsp;       case FileMismatch:

&nbsp;         Serial.println(F("Cannot Find File"));

&nbsp;         break;

&nbsp;       case Advertise:

&nbsp;         Serial.println(F("In Advertise"));

&nbsp;         break;

&nbsp;       default:

&nbsp;         break;

&nbsp;     }

&nbsp;     break;

&nbsp;   default:

&nbsp;     break;

&nbsp; }

&nbsp; 

}

Sample code "FullFunction", including all the functions. Please read the comments and documents in detail

/\*\*\*\*\*\*\*\*\*\*\*\*\*\*\*\*\*\*\*\*\*\*\*\*\*\*\*\*\*\*\*\*\*\*\*\*\*\*\*\*\*\*\*\*\*\*\*\*\*\*\*

&nbsp;DFPlayer - A Mini MP3 Player For Arduino

&nbsp;<https://www.dfrobot.com/product-1121.html>

&nbsp;

&nbsp;\*\*\*\*\*\*\*\*\*\*\*\*\*\*\*\*\*\*\*\*\*\*\*\*\*\*\*\*\*\*\*\*\*\*\*\*\*\*\*\*\*\*\*\*\*\*\*\*\*\*\*

&nbsp;This example shows the all the function of library for DFPlayer.

&nbsp;

&nbsp;Created 2016-12-07

&nbsp;By \[Angelo qiao](Angelo.qiao@dfrobot.com)

&nbsp;

&nbsp;GNU Lesser General Public License.

&nbsp;See <http://www.gnu.org/licenses/> for details.

&nbsp;All above must be included in any redistribution

&nbsp;\*\*\*\*\*\*\*\*\*\*\*\*\*\*\*\*\*\*\*\*\*\*\*\*\*\*\*\*\*\*\*\*\*\*\*\*\*\*\*\*\*\*\*\*\*\*\*\*\*\*\*\*/

/\*\*\*\*\*\*\*\*\*\*\*Notice and Trouble shooting\*\*\*\*\*\*\*\*\*\*\*\*\*\*\*

&nbsp;1.Connection and Diagram can be found here

<https://www.dfrobot.com/wiki/index.php/DFPlayer\_Mini\_SKU:DFR0299#Connection\_Diagram>

&nbsp;2.This code is tested on Arduino Uno, Leonardo, Mega boards.

&nbsp;\*\*\*\*\*\*\*\*\*\*\*\*\*\*\*\*\*\*\*\*\*\*\*\*\*\*\*\*\*\*\*\*\*\*\*\*\*\*\*\*\*\*\*\*\*\*\*\*\*\*\*\*/

\#include "Arduino.h"

\#include "DFRobotDFPlayerMini.h"

\#if (defined(ARDUINO\_AVR\_UNO) || defined(ESP8266))   // Using a soft serial port

\#include <SoftwareSerial.h>

SoftwareSerial softSerial(/\*rx =\*/10, /\*tx =\*/11);

\#define FPSerial softSerial

\#else

\#define FPSerial Serial1

\#endif

DFRobotDFPlayerMini myDFPlayer;

void printDetail(uint8\_t type, int value);

void setup()

{

\#if (defined ESP32)

&nbsp; FPSerial.begin(9600, SERIAL\_8N1, /\*rx =\*/D3, /\*tx =\*/D2);

\#else

&nbsp; FPSerial.begin(9600);

\#endif

&nbsp; Serial.begin(115200);

&nbsp; Serial.println();

&nbsp; Serial.println(F("DFRobot DFPlayer Mini Demo"));

&nbsp; Serial.println(F("Initializing DFPlayer ... (May take 3~5 seconds)"));

&nbsp; 

&nbsp; if (!myDFPlayer.begin(FPSerial, /\*isACK = \*/true, /\*doReset = \*/true)) {  //Use serial to communicate with mp3.

&nbsp;   Serial.println(F("Unable to begin:"));

&nbsp;   Serial.println(F("1.Please recheck the connection!"));

&nbsp;   Serial.println(F("2.Please insert the SD card!"));

&nbsp;   while(true);

&nbsp; }

&nbsp; Serial.println(F("DFPlayer Mini online."));

&nbsp; 

&nbsp; myDFPlayer.setTimeOut(500); //Set serial communictaion time out 500ms

&nbsp; 

&nbsp; //----Set volume----

&nbsp; myDFPlayer.volume(10);  //Set volume value (0~30).

&nbsp; myDFPlayer.volumeUp(); //Volume Up

&nbsp; myDFPlayer.volumeDown(); //Volume Down

&nbsp; 

&nbsp; //----Set different EQ----

&nbsp; myDFPlayer.EQ(DFPLAYER\_EQ\_NORMAL);

//  myDFPlayer.EQ(DFPLAYER\_EQ\_POP);

//  myDFPlayer.EQ(DFPLAYER\_EQ\_ROCK);

//  myDFPlayer.EQ(DFPLAYER\_EQ\_JAZZ);

//  myDFPlayer.EQ(DFPLAYER\_EQ\_CLASSIC);

//  myDFPlayer.EQ(DFPLAYER\_EQ\_BASS);

&nbsp; 

&nbsp; //----Set device we use SD as default----

//  myDFPlayer.outputDevice(DFPLAYER\_DEVICE\_U\_DISK);

&nbsp; myDFPlayer.outputDevice(DFPLAYER\_DEVICE\_SD);

//  myDFPlayer.outputDevice(DFPLAYER\_DEVICE\_AUX);

//  myDFPlayer.outputDevice(DFPLAYER\_DEVICE\_SLEEP);

//  myDFPlayer.outputDevice(DFPLAYER\_DEVICE\_FLASH);

&nbsp; 

&nbsp; //----Mp3 control----

//  myDFPlayer.sleep();     //sleep

//  myDFPlayer.reset();     //Reset the module

//  myDFPlayer.enableDAC();  //Enable On-chip DAC

//  myDFPlayer.disableDAC();  //Disable On-chip DAC

//  myDFPlayer.outputSetting(true, 15); //output setting, enable the output and set the gain to 15

&nbsp; 

&nbsp; //----Mp3 play----

&nbsp; myDFPlayer.next();  //Play next mp3

&nbsp; delay(1000);

&nbsp; myDFPlayer.previous();  //Play previous mp3

&nbsp; delay(1000);

&nbsp; myDFPlayer.play(1);  //Play the first mp3

&nbsp; delay(1000);

&nbsp; myDFPlayer.loop(1);  //Loop the first mp3

&nbsp; delay(1000);

&nbsp; myDFPlayer.pause();  //pause the mp3

&nbsp; delay(1000);

&nbsp; myDFPlayer.start();  //start the mp3 from the pause

&nbsp; delay(1000);

&nbsp; myDFPlayer.playFolder(15, 4);  //play specific mp3 in SD:/15/004.mp3; Folder Name(1~99); File Name(1~255)

&nbsp; delay(1000);

&nbsp; myDFPlayer.enableLoopAll(); //loop all mp3 files.

&nbsp; delay(1000);

&nbsp; myDFPlayer.disableLoopAll(); //stop loop all mp3 files.

&nbsp; delay(1000);

&nbsp; myDFPlayer.playMp3Folder(4); //play specific mp3 in SD:/MP3/0004.mp3; File Name(0~65535)

&nbsp; delay(1000);

&nbsp; myDFPlayer.advertise(3); //advertise specific mp3 in SD:/ADVERT/0003.mp3; File Name(0~65535)

&nbsp; delay(1000);

&nbsp; myDFPlayer.stopAdvertise(); //stop advertise

&nbsp; delay(1000);

&nbsp; myDFPlayer.playLargeFolder(2, 999); //play specific mp3 in SD:/02/004.mp3; Folder Name(1~10); File Name(1~1000)

&nbsp; delay(1000);

&nbsp; myDFPlayer.loopFolder(5); //loop all mp3 files in folder SD:/05.

&nbsp; delay(1000);

&nbsp; myDFPlayer.randomAll(); //Random play all the mp3.

&nbsp; delay(1000);

&nbsp; myDFPlayer.enableLoop(); //enable loop.

&nbsp; delay(1000);

&nbsp; myDFPlayer.disableLoop(); //disable loop.

&nbsp; delay(1000);

&nbsp; //----Read imformation----

&nbsp; Serial.println(myDFPlayer.readState()); //read mp3 state

&nbsp; Serial.println(myDFPlayer.readVolume()); //read current volume

&nbsp; Serial.println(myDFPlayer.readEQ()); //read EQ setting

&nbsp; Serial.println(myDFPlayer.readFileCounts()); //read all file counts in SD card

&nbsp; Serial.println(myDFPlayer.readCurrentFileNumber()); //read current play file number

&nbsp; Serial.println(myDFPlayer.readFileCountsInFolder(3)); //read file counts in folder SD:/03

}

void loop()

{

&nbsp; static unsigned long timer = millis();

&nbsp; 

&nbsp; if (millis() - timer > 3000) {

&nbsp;   timer = millis();

&nbsp;   myDFPlayer.next();  //Play next mp3 every 3 second.

&nbsp; }

&nbsp; 

&nbsp; if (myDFPlayer.available()) {

&nbsp;   printDetail(myDFPlayer.readType(), myDFPlayer.read()); //Print the detail message from DFPlayer to handle different errors and states.

&nbsp; }

}

void printDetail(uint8\_t type, int value){

&nbsp; switch (type) {

&nbsp;   case TimeOut:

&nbsp;     Serial.println(F("Time Out!"));

&nbsp;     break;

&nbsp;   case WrongStack:

&nbsp;     Serial.println(F("Stack Wrong!"));

&nbsp;     break;

&nbsp;   case DFPlayerCardInserted:

&nbsp;     Serial.println(F("Card Inserted!"));

&nbsp;     break;

&nbsp;   case DFPlayerCardRemoved:

&nbsp;     Serial.println(F("Card Removed!"));

&nbsp;     break;

&nbsp;   case DFPlayerCardOnline:

&nbsp;     Serial.println(F("Card Online!"));

&nbsp;     break;

&nbsp;   case DFPlayerUSBInserted:

&nbsp;     Serial.println("USB Inserted!");

&nbsp;     break;

&nbsp;   case DFPlayerUSBRemoved:

&nbsp;     Serial.println("USB Removed!");

&nbsp;     break;

&nbsp;   case DFPlayerPlayFinished:

&nbsp;     Serial.print(F("Number:"));

&nbsp;     Serial.print(value);

&nbsp;     Serial.println(F(" Play Finished!"));

&nbsp;     break;

&nbsp;   case DFPlayerError:

&nbsp;     Serial.print(F("DFPlayerError:"));

&nbsp;     switch (value) {

&nbsp;       case Busy:

&nbsp;         Serial.println(F("Card not found"));

&nbsp;         break;

&nbsp;       case Sleeping:

&nbsp;         Serial.println(F("Sleeping"));

&nbsp;         break;

&nbsp;       case SerialWrongStack:

&nbsp;         Serial.println(F("Get Wrong Stack"));

&nbsp;         break;

&nbsp;       case CheckSumNotMatch:

&nbsp;         Serial.println(F("Check Sum Not Match"));

&nbsp;         break;

&nbsp;       case FileIndexOut:

&nbsp;         Serial.println(F("File Index Out of Bound"));

&nbsp;         break;

&nbsp;       case FileMismatch:

&nbsp;         Serial.println(F("Cannot Find File"));

&nbsp;         break;

&nbsp;       case Advertise:

&nbsp;         Serial.println(F("In Advertise"));

&nbsp;         break;

&nbsp;       default:

&nbsp;         break;

&nbsp;     }

&nbsp;     break;

&nbsp;   default:

&nbsp;     break;

&nbsp; }

&nbsp; 

}

NOTE: The folder name needs to be mp3, placed under the SD card root directory, and the mp3 file name needs to be 4 digits, for example, "0001.mp3", placed under the mp3 folder.

If you want to name it in Both English and Chinese, you can add it after the number, for example, "0001hello.mp3" or "0001后来.mp3".

DFPlayer Mini模块
SKU:DFR0299
DFPlayer Mini

简介
DFPlayer Mini是一款小巧且价格低廉的MP3模块，可以直接接驳扬声器。模块配合供电电池、扬声器、按键可以单独使用，也可以通过串口控制，作为Arduino UNO或者是任何有串口的单片机的一个模块。模块本身完美的集成了MP3、WAV、WMA的硬解码。同时软件支持TF卡驱动，支持FAT16、FAT32文件系统。通过简单的串口指令即可完成播放指定的音乐，以及如何播放音乐等功能，无需繁琐的底层操作，使用方便，稳定可靠。

产品参数
支持采样率(KHz):8/11.025/12/16/22.05/24/32/44.1/48
24位DAC输出，动态范围支持:90dB，信噪比支持:85dB
完全支持FAT16、FAT32文件系统，最大支持32G的TF卡，支持32G的U盘、64M字节的NORFLASH
多种控制模式可选。IO控制模式、串口模式、AD按键控制模式
广播语插播功能，可以暂停正在播放的背景音乐。广告播放完毕回到背景音继续播放
音频数据按文件夹排序，最多支持100个文件夹，每隔文件夹可以分配255首曲目
30级音量可调，6级EQ可调
尺寸: 20mm*20mm
重量: 20g
引脚说明
DFPlayer_Mini_Pin | |

引脚号	引脚名称	功能描述	备注
1	VCC	模块电源输入	3.3V—5V，建议5V，不要超过5.2V
2	RX	UART串行数据输入	
3	TX	UART串行数据输出	
4	DAC_R	音频输出右声道	驱动耳机、功放
5	DAC_L	音频输出左声道	驱动耳机、功放
6	SPK2	接小喇叭	驱动小于3W喇叭
7	GND	地	电源地
8	SPK1	接小喇叭	驱动小于3W喇叭
9	IO1	触发口	默认上一曲（长按音量减）；此引脚短接到地可使歌曲循环播放
10	GND	地	电源地
11	IO2	触发口	默认下一曲（长按音量加）
12	ADKEY1	AD口1	当触发时是第一首（长按循环第一首）
13	ADKEY2	AD口2	当触发时是第五首（长按循环第五首）
14	USB+	USB+ DP	接U盘或插电脑的USB口
15	USB-	USB- DM	接U盘或插电脑的USB口
16	Busy	播放状态	有音频，输出低；无音频，输出高
尺寸图

Arduino使用教程
连线图
DFPlayer_Mini

若使用DFPlayer Mini出现"嘟嘟"的杂音，建议在DFPlayer Mini的Rx与控制器Tx之间串联一个1KΩ电阻

样例代码
库文件下载链接：DFRobotDFPlayerMini
库安装

"GetStarted" 库样例, 每3秒切换下一首
/***************************************************
DFPlayer - A Mini MP3 Player For Arduino
 <https://www.dfrobot.com/product-1121.html>
 
 ***************************************************
 This example shows the basic function of library for DFPlayer.
 
 Created 2016-12-07
 By [Angelo qiao](Angelo.qiao@dfrobot.com)
 
 GNU Lesser General Public License.
 See <http://www.gnu.org/licenses/> for details.
 All above must be included in any redistribution
 ****************************************************/

/***********Notice and Trouble shooting***************
 1.Connection and Diagram can be found here
 <https://www.dfrobot.com/wiki/index.php/DFPlayer_Mini_SKU:DFR0299#Connection_Diagram>
 2.This code is tested on Arduino Uno, Leonardo, Mega boards.
 ****************************************************/

#include "Arduino.h"
#include "DFRobotDFPlayerMini.h"

#if (defined(ARDUINO_AVR_UNO) || defined(ESP8266))   // Using a soft serial port
#include <SoftwareSerial.h>
SoftwareSerial softSerial(/*rx =*/4, /*tx =*/5);
#define FPSerial softSerial
#else
#define FPSerial Serial1
#endif

DFRobotDFPlayerMini myDFPlayer;
void printDetail(uint8_t type, int value);

void setup()
{
#if (defined ESP32)
  FPSerial.begin(9600, SERIAL_8N1, /*rx =*/D3, /*tx =*/D2);
#else
  FPSerial.begin(9600);
#endif

  Serial.begin(115200);

  Serial.println();
  Serial.println(F("DFRobot DFPlayer Mini Demo"));
  Serial.println(F("Initializing DFPlayer ... (May take 3~5 seconds)"));
  
  if (!myDFPlayer.begin(FPSerial, /*isACK = */true, /*doReset = */true)) {  //Use serial to communicate with mp3.
    Serial.println(F("Unable to begin:"));
    Serial.println(F("1.Please recheck the connection!"));
    Serial.println(F("2.Please insert the SD card!"));
    while(true){
      delay(0); // Code to compatible with ESP8266 watch dog.
    }
  }
  Serial.println(F("DFPlayer Mini online."));
  
  myDFPlayer.volume(10);  //Set volume value. From 0 to 30
  myDFPlayer.play(1);  //Play the first mp3
}

void loop()
{
  static unsigned long timer = millis();
  
  if (millis() - timer > 3000) {
    timer = millis();
    myDFPlayer.next();  //Play next mp3 every 3 second.
  }
  
  if (myDFPlayer.available()) {
    printDetail(myDFPlayer.readType(), myDFPlayer.read()); //Print the detail message from DFPlayer to handle different errors and states.
  }
}

void printDetail(uint8_t type, int value){
  switch (type) {
    case TimeOut:
      Serial.println(F("Time Out!"));
      break;
    case WrongStack:
      Serial.println(F("Stack Wrong!"));
      break;
    case DFPlayerCardInserted:
      Serial.println(F("Card Inserted!"));
      break;
    case DFPlayerCardRemoved:
      Serial.println(F("Card Removed!"));
      break;
    case DFPlayerCardOnline:
      Serial.println(F("Card Online!"));
      break;
    case DFPlayerUSBInserted:
      Serial.println("USB Inserted!");
      break;
    case DFPlayerUSBRemoved:
      Serial.println("USB Removed!");
      break;
    case DFPlayerPlayFinished:
      Serial.print(F("Number:"));
      Serial.print(value);
      Serial.println(F(" Play Finished!"));
      break;
    case DFPlayerError:
      Serial.print(F("DFPlayerError:"));
      switch (value) {
        case Busy:
          Serial.println(F("Card not found"));
          break;
        case Sleeping:
          Serial.println(F("Sleeping"));
          break;
        case SerialWrongStack:
          Serial.println(F("Get Wrong Stack"));
          break;
        case CheckSumNotMatch:
          Serial.println(F("Check Sum Not Match"));
          break;
        case FileIndexOut:
          Serial.println(F("File Index Out of Bound"));
          break;
        case FileMismatch:
          Serial.println(F("Cannot Find File"));
          break;
        case Advertise:
          Serial.println(F("In Advertise"));
          break;
        default:
          break;
      }
      break;
    default:
      break;
  }
  
}
"FullFunction" 库样例, 包含了所有的功能, 详见注释以及文档
/***************************************************
 DFPlayer - A Mini MP3 Player For Arduino
 <https://www.dfrobot.com/product-1121.html>
 
 ***************************************************
 This example shows the all the function of library for DFPlayer.
 
 Created 2016-12-07
 By [Angelo qiao](Angelo.qiao@dfrobot.com)
 
 GNU Lesser General Public License.
 See <http://www.gnu.org/licenses/> for details.
 All above must be included in any redistribution
 ****************************************************/

/***********Notice and Trouble shooting***************
 1.Connection and Diagram can be found here
<https://www.dfrobot.com/wiki/index.php/DFPlayer_Mini_SKU:DFR0299#Connection_Diagram>
 2.This code is tested on Arduino Uno, Leonardo, Mega boards.
 ****************************************************/

#include "Arduino.h"
#include "DFRobotDFPlayerMini.h"

#if (defined(ARDUINO_AVR_UNO) || defined(ESP8266))   // Using a soft serial port
#include <SoftwareSerial.h>
SoftwareSerial softSerial(/*rx =*/4, /*tx =*/5);
#define FPSerial softSerial
#else
#define FPSerial Serial1
#endif

DFRobotDFPlayerMini myDFPlayer;
void printDetail(uint8_t type, int value);

void setup()
{
#if (defined ESP32)
  FPSerial.begin(9600, SERIAL_8N1, /*rx =*/D3, /*tx =*/D2);
#else
  FPSerial.begin(9600);
#endif

  Serial.begin(115200);

  Serial.println();
  Serial.println(F("DFRobot DFPlayer Mini Demo"));
  Serial.println(F("Initializing DFPlayer ... (May take 3~5 seconds)"));
  
  if (!myDFPlayer.begin(FPSerial, /*isACK = */true, /*doReset = */true)) {  //Use serial to communicate with mp3.
    Serial.println(F("Unable to begin:"));
    Serial.println(F("1.Please recheck the connection!"));
    Serial.println(F("2.Please insert the SD card!"));
    while(true);
  }
  Serial.println(F("DFPlayer Mini online."));
  
  myDFPlayer.setTimeOut(500); //Set serial communictaion time out 500ms
  
  //----Set volume----
  myDFPlayer.volume(10);  //Set volume value (0~30).
  myDFPlayer.volumeUp(); //Volume Up
  myDFPlayer.volumeDown(); //Volume Down
  
  //----Set different EQ----
  myDFPlayer.EQ(DFPLAYER_EQ_NORMAL);
//  myDFPlayer.EQ(DFPLAYER_EQ_POP);
//  myDFPlayer.EQ(DFPLAYER_EQ_ROCK);
//  myDFPlayer.EQ(DFPLAYER_EQ_JAZZ);
//  myDFPlayer.EQ(DFPLAYER_EQ_CLASSIC);
//  myDFPlayer.EQ(DFPLAYER_EQ_BASS);
  
  //----Set device we use SD as default----
//  myDFPlayer.outputDevice(DFPLAYER_DEVICE_U_DISK);
  myDFPlayer.outputDevice(DFPLAYER_DEVICE_SD);
//  myDFPlayer.outputDevice(DFPLAYER_DEVICE_AUX);
//  myDFPlayer.outputDevice(DFPLAYER_DEVICE_SLEEP);
//  myDFPlayer.outputDevice(DFPLAYER_DEVICE_FLASH);
  
  //----Mp3 control----
//  myDFPlayer.sleep();     //sleep
//  myDFPlayer.reset();     //Reset the module
//  myDFPlayer.enableDAC();  //Enable On-chip DAC
//  myDFPlayer.disableDAC();  //Disable On-chip DAC
//  myDFPlayer.outputSetting(true, 15); //output setting, enable the output and set the gain to 15
  
  //----Mp3 play----
  myDFPlayer.next();  //Play next mp3
  delay(1000);
  myDFPlayer.previous();  //Play previous mp3
  delay(1000);
  myDFPlayer.play(1);  //Play the first mp3
  delay(1000);
  myDFPlayer.loop(1);  //Loop the first mp3
  delay(1000);
  myDFPlayer.pause();  //pause the mp3
  delay(1000);
  myDFPlayer.start();  //start the mp3 from the pause
  delay(1000);
  myDFPlayer.playFolder(15, 4);  //play specific mp3 in SD:/15/004.mp3; Folder Name(1~99); File Name(1~255)
  delay(1000);
  myDFPlayer.enableLoopAll(); //loop all mp3 files.
  delay(1000);
  myDFPlayer.disableLoopAll(); //stop loop all mp3 files.
  delay(1000);
  myDFPlayer.playMp3Folder(4); //play specific mp3 in SD:/MP3/0004.mp3; File Name(0~65535)
  delay(1000);
  myDFPlayer.advertise(3); //advertise specific mp3 in SD:/ADVERT/0003.mp3; File Name(0~65535)
  delay(1000);
  myDFPlayer.stopAdvertise(); //stop advertise
  delay(1000);
  myDFPlayer.playLargeFolder(2, 999); //play specific mp3 in SD:/02/004.mp3; Folder Name(1~10); File Name(1~1000)
  delay(1000);
  myDFPlayer.loopFolder(5); //loop all mp3 files in folder SD:/05.
  delay(1000);
  myDFPlayer.randomAll(); //Random play all the mp3.
  delay(1000);
  myDFPlayer.enableLoop(); //enable loop.
  delay(1000);
  myDFPlayer.disableLoop(); //disable loop.
  delay(1000);

  //----Read imformation----
  Serial.println(myDFPlayer.readState()); //read mp3 state
  Serial.println(myDFPlayer.readVolume()); //read current volume
  Serial.println(myDFPlayer.readEQ()); //read EQ setting
  Serial.println(myDFPlayer.readFileCounts()); //read all file counts in SD card
  Serial.println(myDFPlayer.readCurrentFileNumber()); //read current play file number
  Serial.println(myDFPlayer.readFileCountsInFolder(3)); //read file counts in folder SD:/03
}

void loop()
{
  static unsigned long timer = millis();
  
  if (millis() - timer > 3000) {
    timer = millis();
    myDFPlayer.next();  //Play next mp3 every 3 second.
  }
  
  if (myDFPlayer.available()) {
    printDetail(myDFPlayer.readType(), myDFPlayer.read()); //Print the detail message from DFPlayer to handle different errors and states.
  }
}

void printDetail(uint8_t type, int value){
  switch (type) {
    case TimeOut:
      Serial.println(F("Time Out!"));
      break;
    case WrongStack:
      Serial.println(F("Stack Wrong!"));
      break;
    case DFPlayerCardInserted:
      Serial.println(F("Card Inserted!"));
      break;
    case DFPlayerCardRemoved:
      Serial.println(F("Card Removed!"));
      break;
    case DFPlayerCardOnline:
      Serial.println(F("Card Online!"));
      break;
    case DFPlayerUSBInserted:
      Serial.println("USB Inserted!");
      break;
    case DFPlayerUSBRemoved:
      Serial.println("USB Removed!");
      break;
    case DFPlayerPlayFinished:
      Serial.print(F("Number:"));
      Serial.print(value);
      Serial.println(F(" Play Finished!"));
      break;
    case DFPlayerError:
      Serial.print(F("DFPlayerError:"));
      switch (value) {
        case Busy:
          Serial.println(F("Card not found"));
          break;
        case Sleeping:
          Serial.println(F("Sleeping"));
          break;
        case SerialWrongStack:
          Serial.println(F("Get Wrong Stack"));
          break;
        case CheckSumNotMatch:
          Serial.println(F("Check Sum Not Match"));
          break;
        case FileIndexOut:
          Serial.println(F("File Index Out of Bound"));
          break;
        case FileMismatch:
          Serial.println(F("Cannot Find File"));
          break;
        case Advertise:
          Serial.println(F("In Advertise"));
          break;
        default:
          break;
      }
      break;
    default:
      break;
  }
  
}
**注意**：文件夹命名需要是mp3，放置在SD卡根目录下，而mp3文件命名需要是4位数字，例如"0001.mp3"，放置在mp3文件夹下。

如需中英文命名，可以添加在数字后，例如"0001hello.mp3"或者"0001后来.mp3"。

Mind+（基于Scratch3.0）图形化编程代码使用教程
在相同的接线情况下，使用Mind+软件进行图形化编程， 前往-Mind+下载和安装

首先在Mind+中选择MP3功能模块，“扩展”-“执行器”-“MP3模块”

DFPlayer_Mini

主要功能模块如下：

主要功能

使用UART软串口模式进行相应的编程：

程序接线：

使用UART硬串口模式进行相应的编程：

程序接线：

若使用DFPlayer Mini出现"嘟嘟"的杂音，建议在DFPlayer Mini的Rx与控制器Tx之间串联一个1KΩ电阻

资料说明
串口模式
模块支持异步串口通讯模式,通过串口接受控制命令

串口指令格式
指令名称	对应功能	功能描述
$S	起始位0x7E	每条命令反馈均以$开头，即0x7E
VER	版本	版本信息[目前默认为0xFF]
Len	len后字节个数	校验和不计算在内
CMD	命令字	表示具体的操作，比如播放/暂停等等
Feedback	命令反馈	是否需要反馈信息，1反馈，0不反馈
para1	参数1	查询的数据高字节（比如歌曲序号）
para2	参数2	查询的数据低字节
checksum	校验和[占两个字节]	累加和校验[不计起始位$]
$0	结束位	结束位0xEF
举个例子，如果我们制定播放NOR FLASH，就需要发送:7E FF 06 09 00 00 04 FE EE EF,数据长度为6，这6个字节分别是[FF 06 09 00 00 04]。 不计算起始、结束、和校验。再然后对得到的结果进行取反。

串口控制指令
CMD命令(指令)	对应的功能	参数（16位）
0x01	下一曲	
0x02	上一曲	
0x03	指定曲目（NUM）	1-2999
0x04	音量+	
0x05	音量-	
0x06	指定音量	0-30
0x07	指定EQ 0/1/2/3/4/5	Normal/Pop/Rock/Jazz/Classic/Bass
0x08	单曲循环指定曲目播放	1-2999
0x09	指定播放设备 1/2/3/4/5	U盘/SD/AUX/SLEEP/FLASH
0x0A	进入休眠——低功耗	
0x0B	保留	
0x0C	模块复位	
0x0D	播放	
0x0E	暂停	
0x0F	指定文件夹播放	1-10（需要自己设定）
0x10	扩音设置（无）	[DH=1:开扩音][DL:设置增益0-31]
0x11	全部循环播放	[1:循环播放][0:停止循环播放]
0x12	指定MP3文件夹曲目	1-9999
0x13	插播广告	1-9999
0x14	支持15个文件夹	见下面的详细说明
0x15	停止播放，播放背景	
0x16	停止播放	
串口查询指令
CMD命令详解(指令)	对应的功能	参数（16位）
0x3C	STAY	
0x3D	STAY	
0x3E	STAY	
0x3F	发送初始化参数	0-0x0F（低四位每位代表一种设备）
0x40	返回错误，请求重发	
0x41	应答	
0x42	查询当前状态	
0x43	查询当前音量	
0x44	查询当前EQ	
0x45	查询当前播放模式	该版本保留此功能
0x46	查询当前软件版本	该版本保留此功能
0x47	查询UDISK的总文件数	
0x48	查询TF卡的总文件数	
0x49	查询FLASH卡的总文件数	
0x4A	保留	
0x4B	查询UDISK的当前曲目	
0x4C	查询TF的当前曲目	
0x4D	查询FLASH的当前曲目	
串口使用过程
串口连接线路图

DFPlayer_Mini

.打开sscom，连接USB serial。

2.在串口发送指令就能对mini进行控制使用了。

DFPlayer_Mini

AD按键模式
模块还支持AD按键控制方式，取代了传统了矩阵键盘的接法，这样做的好处是充分利用了MCU越来越强大的AD功能。设计简约而不简单，我们模块默认配置2个AD口，20个按键的阻值分配。
AD按键购买链接

按键使用示意原理图
DFPlayer_Mini

IO模式
本模块也支持简单的IO模式

DFPlayer_Mini

PS:短按：低电平时间约为200ms

疑难解答
**问 ：**Arduino控制DFPlayer mini时，喇叭有杂音，如何处理？ |

**答：**在TX，RX与MP3模块的RX，TX之间连一个1k电阻。因为DFPlayer Mini模块工作电压应该是3.3V，而主控板传入电压为5V，因此需要1K左右电阻分压。
答： 如果效果不好，可以在mp3播放的代码后面增加一条语句，将RX引脚置为低电平。
**问 ：**为什么 play(1) 播放的不是 0001.mp3, 而是其他的的音乐? 为什么播放的顺序不是按照文件名播放? |

**答：**play(1)是播放TF卡中的第一首歌, 播放顺序是由mp3放入TF卡的顺序决定的, 而不是按照文件名排序播放的, 如果需要按照文件名播放, 可以参考下面的playMp3Folder(1)
**问 ：**是否可以按照文件名播放? |

答：可以使用函数playMp3Folder (1); 播放文件的格式为"0001***.mp3(或支持其他格式)". 您可能需要注意这些:
(1). 该音频文件的名称应该命名一个四位数字开始，如：

0001.mp3
0002Chasing The Sun.mp3
0003.mp3

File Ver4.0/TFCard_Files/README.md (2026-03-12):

# TFCard_Files 说明（Ver4.0）

## 1) 快速开始

- **请将`TFCard_Files`整个文件夹内部所有文件复制与TF卡根目录后，插入MP3模块。**
- `MP3/`：唯一音频目录（位于 TF 卡根目录）
- `mp3module.md`：模块指令说明

完成以上步骤后即为配置完成

---

注：以下内容是写给开发人员或需要添加新音乐盒等等时才用到的说明。

## 2) 文件命名规则（统一 4 位前缀）

### `0xxx`：播报与纯爆炸音效

- `0101.MP3`：下包成功（arm success）
- `0102.MP3`：纯爆炸音效（explosion only）
- `0103.MP3`：拆弹成功（bomb defused）
- `0104.MP3`：CT 胜利播报（ctwin）
- `0105.MP3`：T 胜利播报（terwin）

### `1xxx`：CT 音乐盒

- 规则：`0abc` → `1abc`
- 示例：`0001.MP3` → `1001.MP3`

### `2xxx`：T 爆炸+音乐盒

- 规则：`0abc` → `2abc`
- 示例：`0001.MP3` → `2001.MP3`

### 音乐序号

```
		音乐序号  音乐名
			0	虚空
			1	军团
			2	新黑色电影
			3	困兽
			4	神枪手
			5   	追溯起源
			6   	竞技场
			7	冲破藩篱
			8	咄咄逼人
			9	哥特浮华
			10	大胆尝试
			11	GLA
			12	漂泊者
			13	战火星空
			14	黄色魔法
			15	巨龙之眼
			16	咖啡拉花
			17	巴克拉姆
			18	电锯追命
			19	决心
			20	燥起来
			21	尘归尘
			22	A.D.8
			23	疤王
			24	万夫莫敌包
			25	终极
			26	大局入侵
			27	同型节奏
			28	地球末夜
			29	莫洛托夫烈火
			30	无人之境
			31	理由
			32	精彩时刻
			33	超爆话筒
			34	叛乱
			35	雄狮之口
			36	沙漠之焰
			37	好好干，好好活
			38	深红突击
			39	骷髅爆破
			40	绝对统御
			41	金属
			42	如日中天
			43	永恒之钻
			44	圣诞之歌
			45	你急了
			46	蜂鸟
			47	海绵手指
			48	8位音乐盒
			49	迈阿密热线
			50	令人发指
			51	躺平青年
			52	爆头
			53	闪光舞
			54	尖峰时刻
			55	塔罗斯的法则
			56	有害物质环境
			57	就是我
			58	EZ4ENCE
			59	爪哇哈瓦那放克乐
			60	触摸能量
			61	通宵达旦
			62	非人类
			63	花脸
			64	征服
			65	万众瞩目
			66	冲击星
			67	人生何处不青山
			68	枪炮卷饼卡车
			69	有为青年
			70	光环：士官长合集
			71	黑帝斯音乐盒
			72	反叛者
			73	Ben Bromfield,Rabbit Hole
			74	Daniel Sadowski,Dead Shot
			75	Sam Marshall,Clutch
			76	Tree Adams,Seventh Moon
			77	Tim Huling,Devil's Paintbrush
			78	Dren McDonald,Coffee!Kofe Kahveh!
			79	Matt Levine,Agency
			80	Austin Wintory,The Devil Went Clubbing in Georgia
			81	诶嘿
            82  Adam Beyer, Red Boom
```

---

## 3) 编号与配置的关系（重点）

用户配置仍使用“三位编号”（`0~999`），不需要手动写 `1xxx/2xxx` 的前缀位：

- `CONFIG_MP3_CT_WIN_MUSICBOX_TRACK = n` 对应播放 `1nnn.MP3`
- `CONFIG_MP3_T_WIN_MUSICBOX_TRACK = n` 对应播放 `2nnn.MP3`

固定播报编号使用 `0xxx`：

- `CONFIG_MP3_TRACK_ARM_SUCCESS = 101`
- `CONFIG_MP3_TRACK_EXPLOSION = 102`
- `CONFIG_MP3_TRACK_DEFUSE_SUCCESS = 103`
- `CONFIG_MP3_TRACK_CTWIN = 104`
- `CONFIG_MP3_TRACK_TERWIN = 105`

---

## 4) 播放流程（代码当前实现）

1. 上电：不播放 MP3，仅蜂鸣（可开关）
2. 下包成功：可选播放 `0101`
3. 拆弹成功阶段：
   - 播放 `0103`
   - 等待 `CONFIG_MP3_DEFUSE_SUCCESS_WAIT_MS`
   - 可选播放 `1nnn`
   - 等待 `CONFIG_MP3_CT_MUSICBOX_WAIT_MS`（仅启用 CT 音乐盒时）
   - 可选播放 `0104`
4. 爆炸阶段：
   - 若启用 T 音乐盒：播放 `2nnn`，等待 `CONFIG_MP3_T_MUSICBOX_WAIT_MS`，再可选 `0105`
   - 否则播放 `0102`，等待 `CONFIG_MP3_EXPLOSION_ONLY_WAIT_MS`，再可选 `0105`

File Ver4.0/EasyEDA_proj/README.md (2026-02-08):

# EasyEDA 工程说明 / EasyEDA Project Notes

## 中文

本目录收录 EasyEDA 原始工程文件，当前文件名为 `ProPrj_CS2-C4_V4.1.epro2`。

尽管文件版本标注为 **V4.1**，其设计内容与本仓库 `Ver4.0` 目录对应的版本兼容，可用于 `Ver4.0` 的工程查阅、复核与后续编辑。

如需在线查看或对照硬件开源页面，亦可访问 OSHWHUB：
https://oshwhub.com/azidopp/CS2-C4

## English

This directory contains the original EasyEDA project file: `ProPrj_CS2-C4_V4.1.epro2`.

Although the file is labeled **V4.1**, its design remains compatible with the version documented under `Ver4.0` in this repository, and can be used for review, verification, and subsequent edits for `Ver4.0`.

For online access and cross-reference, you may also visit the OSHWHUB page:
https://oshwhub.com/azidopp/CS2-C4

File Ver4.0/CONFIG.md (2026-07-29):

# Ver4.0 配置说明 / Configuration Guide

## 中文（教程 + 完整配置）

### 快速教程（不重新下载程序也能改配置）
1. 先按住 `#` 不放。
2. 在按住 `#` 的同时，按一下 `RESET`（或重新上电）。
3. 继续按住 `#` 约 1 秒，直到屏幕进入配置界面。

### 修改一个配置
1. 输入配置编号（例如 `24`）。
2. 按 `#` 确认编号。
3. 输入新数值（例如 `500`）。
4. 按 `#` 进入保存确认。
5. 再按一次 `#` 保存。
6. 屏幕出现 `STORED` 后，按 `RESET`。

### 按键说明
- `0~9`：输入数字
- `*`：删掉最后一位
- `#`：确认当前步骤

### 恢复出厂设置
- 输入 `090405`，再按 `#` 确认恢复。

### 示例
- 把 `CONFIG_LONG_PRESS_MS`（编号 `24`）改成 `500`：进入配置模式 -> 输入 `24` -> `#` -> 输入 `500` -> `#` -> `#` 保存 -> `RESET`。

### 配置总表（中文）
| 编号 | 配置名 | 说明 | 默认值 | 范围 / 选项（典型） |
|---:|---|---|---|---|
| 0 | `CONFIG_IGNORE_RANGE` | 是否忽略范围检查 | `0` | `0/1` |
| 1 | `CONFIG_PASSWORD_LEN` | 密码长度（位） | `7` | `1..16`（典型 `7`） |
| 2 | `CONFIG_LCD_COLS` | LCD 列数 | `16` | `8..16`（典型 `16`） |
| 3 | `CONFIG_LCD_NORMAL_MOUNT` | LCD 安装方向 | `0` | `0=倒装, 1=正装` |
| 4 | `CONFIG_PASSWORD_COL` | 密码起始列 | `3` | `0..(LCD_COLS-PASSWORD_LEN)`（典型 `3`） |
| 5 | `CONFIG_COUNTDOWN_MS` | 倒计时毫秒数 | `40000` | `>=1000`（典型 `40000`） |
| 6 | `CONFIG_ARM_DELAY_MS` | 下包前最后按键延迟（毫秒） | `800` | `0..5000`（典型 `800`） |
| 7 | `CONFIG_ARM_PRESET_ENABLE` | 是否启用固定下包密码 | `0` | `0/1` |
| 8 | `CONFIG_ARM_PRESET_PASSWORD` | 固定下包密码 | `7355608` | 仅数字；启用固定密码时长度必须等于密码长度 |
| 9 | `CONFIG_DEFUSE_ENABLE_PASSWORD` | 是否启用密码拆弹 | `0` | `0/1` |
| 10 | `CONFIG_DEFUSE_ENABLE_MANUAL` | 是否启用长按 `#` 拆弹 | `1` | `0/1` |
| 11 | `CONFIG_DEFUSE_ENABLE_EXTERNAL` | 是否启用外部拆弹器 | `1` | `0/1` |
| 12 | `CONFIG_LCD_BACKLIGHT_PCT` | LCD 背光亮度百分比 | `50` | `0..100`（典型 `50`） |
| 13 | `CONFIG_BEEP_LEN_MS` | 倒计时每次蜂鸣时长（毫秒） | `125` | `10..500`（典型 `125`） |
| 14 | `CONFIG_BEEP_INTERVAL_BASE_MS` | 蜂鸣基础间隔（毫秒） | `100` | `10..1000`（典型 `100`） |
| 15 | `CONFIG_BEEP_INTERVAL_SCALE_MS` | 蜂鸣间隔缩放（毫秒） | `900` | `0..2000`（典型 `900`） |
| 16 | `CONFIG_BEEP_INTERVAL_MIN_MS` | 蜂鸣最小间隔（毫秒） | `150` | `50..1000`（典型 `150`） |
| 17 | `CONFIG_BEEP_INITIAL_MS` | 首次蜂鸣延迟（毫秒） | `1000` | `0..5000`（典型 `1000`） |
| 18 | `CONFIG_LED_PWM_MAX` | LED 最大亮度级别 | `1000` | `100..10000`（典型 `1000`） |
| 19 | `CONFIG_LED_BREATH_PERIOD_MS` | 待机呼吸周期（毫秒） | `700` | `100..5000`（典型 `700`） |
| 20 | `CONFIG_LED_YELLOW_RED_PCT` | 黄色中红灯比例（百分比） | `40` | `0..100`（典型 `40`） |
| 21 | `CONFIG_SCROLL_INTERVAL_MS` | 滚动动画刷新间隔（毫秒） | `50` | `10..500`（典型 `50`） |
| 22 | `CONFIG_SCROLL_PATTERN_LEN` | 滚动图案长度 | `3` | `1..16`（典型 `3`） |
| 23 | `CONFIG_DIGITAL_COUNTDOWN_ENABLE` | 是否显示数字倒计时 | `0` | `0/1` |
| 24 | `CONFIG_LONG_PRESS_MS` | 长按阈值（毫秒） | `200` | `200..3000`（典型 `200`） |
| 25 | `CONFIG_MANUAL_DEFUSE_MS` | 手动拆弹总时长（毫秒） | `10000` | `>=1000`（典型 `10000`） |
| 26 | `CONFIG_EXTERNAL_DEFUSE_MS` | 外部拆弹总时长（毫秒） | `5000` | `>=1000`（典型 `5000`） |
| 27 | `CONFIG_DEFUSE_DISPLAY_HOLD_MS` | 拆弹显示保持时长（毫秒） | `1200` | `200..5000`（典型 `1200`） |
| 28 | `CONFIG_DEFUSE_CYCLE_STEPS` | 拆弹循环步数 | `10` | `1..20`（典型 `10`） |
| 29 | `CONFIG_DEFUSE_FLASH_TOGGLE_MS` | 拆弹成功闪烁切换间隔（毫秒） | `10` | `10..200`（典型 `10`） |
| 30 | `CONFIG_DEFUSE_FLASH_TOGGLES` | 拆弹成功闪烁次数 | `8` | `1..20`（典型 `8`） |
| 31 | `CONFIG_DEFUSE_BLINK_MS` | 拆弹成功加号/减号/密码帧间隔（毫秒） | `400` | `100..1000`（典型 `400`） |
| 32 | `CONFIG_BUZZER_STARTUP_FREQ_HZ` | 上电蜂鸣频率（Hz） | `4250` | `100..10000`（典型 `4250`） |
| 33 | `CONFIG_BUZZER_COUNTDOWN_FREQ_HZ` | 倒计时蜂鸣频率（Hz） | `3600` | `100..10000`（典型 `3600`） |
| 34 | `CONFIG_BUZZER_DUTY_PCT` | 蜂鸣占空比（百分比） | `50` | `0..50`（典型 `50`） |
| 35 | `CONFIG_STARTUP_BEEP_ON_MS` | 上电蜂鸣开启时长（毫秒） | `50` | `10..500`（典型 `50`） |
| 36 | `CONFIG_STARTUP_BEEP_GAP_MS` | 上电蜂鸣间隔时长（毫秒） | `50` | `10..500`（典型 `50`） |
| 37 | `CONFIG_STARTUP_BEEP_ENABLE` | 是否启用上电蜂鸣 | `1` | `0/1` |
| 38 | `CONFIG_MP3_VOLUME` | MP3 音量 | `25` | `0..30`（典型 `25`） |
| 39 | `CONFIG_MP3_ARM_SUCCESS_ENABLE` | 下包成功播报开关 | `1` | `0/1` |
| 40 | `CONFIG_MP3_DEFUSE_SUCCESS_ENABLE` | 拆弹成功播报开关 | `1` | `0/1` |
| 41 | `CONFIG_MP3_TRACK_ARM_SUCCESS` | 下包成功播报号 | `101` | `1..999`（典型 `101`） |
| 42 | `CONFIG_MP3_TRACK_EXPLOSION` | 爆炸音效号 | `102` | `1..999`（典型 `102`） |
| 43 | `CONFIG_MP3_TRACK_DEFUSE_SUCCESS` | 拆弹成功播报号 | `103` | `1..999`（典型 `103`） |
| 44 | `CONFIG_MP3_TRACK_CTWIN` | CT 胜利播报号 | `104` | `1..999`（典型 `104`） |
| 45 | `CONFIG_MP3_TRACK_TERWIN` | T 胜利播报号 | `105` | `1..999`（典型 `105`） |
| 46 | `CONFIG_MP3_DEFUSE_STAGE_ENABLE` | 拆弹成功阶段 MP3 总开关 | `1` | `0/1` |
| 47 | `CONFIG_MP3_EXPLODED_STAGE_ENABLE` | 爆炸阶段 MP3 总开关 | `1` | `0/1` |
| 48 | `CONFIG_MP3_EXPLOSION_ENABLE` | 爆炸音效开关 | `1` | `0/1` |
| 49 | `CONFIG_MP3_CT_WIN_MUSICBOX_ENABLE` | CT 音乐盒开关 | `1` | `0/1` |
| 50 | `CONFIG_MP3_T_WIN_MUSICBOX_ENABLE` | T 音乐盒开关 | `1` | `0/1` |
| 51 | `CONFIG_MP3_CTWIN_ENABLE` | CT 胜利播报开关 | `1` | `0/1` |
| 52 | `CONFIG_MP3_TERWIN_ENABLE` | T 胜利播报开关 | `1` | `0/1` |
| 53 | `CONFIG_MP3_CT_WIN_MUSICBOX_TRACK` | CT 音乐盒编号 | `10` | `0..999`（典型 `10`） |
| 54 | `CONFIG_MP3_T_WIN_MUSICBOX_TRACK` | T 音乐盒编号 | `1` | `0..999`（典型 `1`） |
| 55 | `CONFIG_MP3_DEFUSE_SUCCESS_WAIT_MS` | 拆弹播报后等待时长（毫秒） | `2700` | `0..20000`（典型 `2700`） |
| 56 | `CONFIG_MP3_CT_MUSICBOX_WAIT_MS` | CT 音乐盒后等待时长（毫秒） | `9000` | `0..20000`（典型 `9000`） |
| 57 | `CONFIG_MP3_T_MUSICBOX_WAIT_MS` | T 音乐盒后等待时长（毫秒） | `10000` | `0..20000`（典型 `10000`） |
| 58 | `CONFIG_MP3_EXPLOSION_ONLY_WAIT_MS` | 爆炸音效后等待时长（毫秒） | `7000` | `0..20000`（典型 `7000`） |
| 59 | `CONFIG_EXPLOSION_BEEP_MS` | 倒计时结束后、爆炸流程前的预蜂鸣时长（毫秒） | `500` | `0..5000`（典型 `500`） |
| 60 | `CONFIG_ARM_ERROR_HINT_ENABLE` | 固定下包密码错误时是否显示 `ERROR` | `0` | `0=静默清空, 1=显示ERROR后清空` |

### 附：音乐序号

```
		音乐序号  音乐名
			0	虚空
			1	军团
			2	新黑色电影
			3	困兽
			4	神枪手
			5   	追溯起源
			6   	竞技场
			7	冲破藩篱
			8	咄咄逼人
			9	哥特浮华
			10	大胆尝试
			11	GLA
			12	漂泊者
			13	战火星空
			14	黄色魔法
			15	巨龙之眼
			16	咖啡拉花
			17	巴克拉姆
			18	电锯追命
			19	决心
			20	燥起来
			21	尘归尘
			22	A.D.8
			23	疤王
			24	万夫莫敌包
			25	终极
			26	大局入侵
			27	同型节奏
			28	地球末夜
			29	莫洛托夫烈火
			30	无人之境
			31	理由
			32	精彩时刻
			33	超爆话筒
			34	叛乱
			35	雄狮之口
			36	沙漠之焰
			37	好好干，好好活
			38	深红突击
			39	骷髅爆破
			40	绝对统御
			41	金属
			42	如日中天
			43	永恒之钻
			44	圣诞之歌
			45	你急了
			46	蜂鸟
			47	海绵手指
			48	8位音乐盒
			49	迈阿密热线
			50	令人发指
			51	躺平青年
			52	爆头
			53	闪光舞
			54	尖峰时刻
			55	塔罗斯的法则
			56	有害物质环境
			57	就是我
			58	EZ4ENCE
			59	爪哇哈瓦那放克乐
			60	触摸能量
			61	通宵达旦
			62	非人类
			63	花脸
			64	征服
			65	万众瞩目
			66	冲击星
			67	人生何处不青山
			68	枪炮卷饼卡车
			69	有为青年
			70	光环：士官长合集
			71	黑帝斯音乐盒
			72	反叛者
			73	Ben Bromfield,Rabbit Hole
			74	Daniel Sadowski,Dead Shot
			75	Sam Marshall,Clutch
			76	Tree Adams,Seventh Moon
			77	Tim Huling,Devil's Paintbrush
			78	Dren McDonald,Coffee!Kofe Kahveh!
			79	Matt Levine,Agency
			80	Austin Wintory,The Devil Went Clubbing in Georgia
			81	诶嘿
            82  Adam Beyer, Red Boom
```

---

## English (Tutorial + Full Config List)

### Quick Tutorial (change settings without re-uploading code)
1. Hold `#`.
2. While holding `#`, press `RESET` (or power cycle).
3. Keep holding `#` for about 1 second until config screen appears.

### Change one config item
1. Enter the config ID (example: `24`).
2. Press `#` to confirm the ID.
3. Enter the new value (example: `500`).
4. Press `#` to go to save confirmation.
5. Press `#` again to save.
6. When `STORED` appears, press `RESET`.

### Keys
- `0~9`: input digits
- `*`: delete last digit
- `#`: confirm current step

### Restore factory settings
- Enter `090405`, then press `#` to confirm restore.

### Example
- Set `CONFIG_LONG_PRESS_MS` (ID `24`) to `500`: enter config mode -> `24` -> `#` -> `500` -> `#` -> `#` save -> `RESET`.

### Full Config Table (English)
| ID | Name | Description | Default | Range / Options (Typical) |
|---:|---|---|---|---|
| 0 | `CONFIG_IGNORE_RANGE` | Ignore range checking | `0` | `0/1` |
| 1 | `CONFIG_PASSWORD_LEN` | Password length (digits) | `7` | `1..16` (typical `7`) |
| 2 | `CONFIG_LCD_COLS` | LCD columns | `16` | `8..16` (typical `16`) |
| 3 | `CONFIG_LCD_NORMAL_MOUNT` | LCD mount orientation | `0` | `0=inverted, 1=normal` |
| 4 | `CONFIG_PASSWORD_COL` | Password start column | `3` | `0..(LCD_COLS-PASSWORD_LEN)` (typical `3`) |
| 5 | `CONFIG_COUNTDOWN_MS` | Countdown duration (ms) | `40000` | `>=1000` (typical `40000`) |
| 6 | `CONFIG_ARM_DELAY_MS` | Delay after last key before arming (ms) | `800` | `0..5000` (typical `800`) |
| 7 | `CONFIG_ARM_PRESET_ENABLE` | Require preset password to arm | `0` | `0/1` |
| 8 | `CONFIG_ARM_PRESET_PASSWORD` | Preset arm password | `7355608` | Digits only; if preset enabled, length must equal password length |
| 9 | `CONFIG_DEFUSE_ENABLE_PASSWORD` | Enable password defuse | `0` | `0/1` |
| 10 | `CONFIG_DEFUSE_ENABLE_MANUAL` | Enable long-press `#` defuse | `1` | `0/1` |
| 11 | `CONFIG_DEFUSE_ENABLE_EXTERNAL` | Enable external defuser | `1` | `0/1` |
| 12 | `CONFIG_LCD_BACKLIGHT_PCT` | LCD backlight percent | `50` | `0..100` (typical `50`) |
| 13 | `CONFIG_BEEP_LEN_MS` | Countdown beep ON length (ms) | `125` | `10..500` (typical `125`) |
| 14 | `CONFIG_BEEP_INTERVAL_BASE_MS` | Base beep interval (ms) | `100` | `10..1000` (typical `100`) |
| 15 | `CONFIG_BEEP_INTERVAL_SCALE_MS` | Beep interval scaling (ms) | `900` | `0..2000` (typical `900`) |
| 16 | `CONFIG_BEEP_INTERVAL_MIN_MS` | Minimum beep interval (ms) | `150` | `50..1000` (typical `150`) |
| 17 | `CONFIG_BEEP_INITIAL_MS` | Initial beep delay (ms) | `1000` | `0..5000` (typical `1000`) |
| 18 | `CONFIG_LED_PWM_MAX` | LED max brightness level | `1000` | `100..10000` (typical `1000`) |
| 19 | `CONFIG_LED_BREATH_PERIOD_MS` | Idle breathing period (ms) | `700` | `100..5000` (typical `700`) |
| 20 | `CONFIG_LED_YELLOW_RED_PCT` | Red ratio in yellow color (%) | `40` | `0..100` (typical `40`) |
| 21 | `CONFIG_SCROLL_INTERVAL_MS` | Scroll animation update interval (ms) | `50` | `10..500` (typical `50`) |
| 22 | `CONFIG_SCROLL_PATTERN_LEN` | Scroll pattern length | `3` | `1..16` (typical `3`) |
| 23 | `CONFIG_DIGITAL_COUNTDOWN_ENABLE` | Enable digital countdown display | `0` | `0/1` |
| 24 | `CONFIG_LONG_PRESS_MS` | Long-press threshold (ms) | `200` | `200..3000` (typical `200`) |
| 25 | `CONFIG_MANUAL_DEFUSE_MS` | Manual defuse total duration (ms) | `10000` | `>=1000` (typical `10000`) |
| 26 | `CONFIG_EXTERNAL_DEFUSE_MS` | External defuse total duration (ms) | `5000` | `>=1000` (typical `5000`) |
| 27 | `CONFIG_DEFUSE_DISPLAY_HOLD_MS` | Defuse display hold time (ms) | `1200` | `200..5000` (typical `1200`) |
| 28 | `CONFIG_DEFUSE_CYCLE_STEPS` | Defuse cycle steps | `10` | `1..20` (typical `10`) |
| 29 | `CONFIG_DEFUSE_FLASH_TOGGLE_MS` | Defuse-success flash toggle interval (ms) | `10` | `10..200` (typical `10`) |
| 30 | `CONFIG_DEFUSE_FLASH_TOGGLES` | Defuse-success flash toggle count | `8` | `1..20` (typical `8`) |
| 31 | `CONFIG_DEFUSE_BLINK_MS` | Defuse-success plus/minus/code frame interval (ms) | `400` | `100..1000` (typical `400`) |
| 32 | `CONFIG_BUZZER_STARTUP_FREQ_HZ` | Startup buzzer frequency (Hz) | `4250` | `100..10000` (typical `4250`) |
| 33 | `CONFIG_BUZZER_COUNTDOWN_FREQ_HZ` | Countdown buzzer frequency (Hz) | `3600` | `100..10000` (typical `3600`) |
| 34 | `CONFIG_BUZZER_DUTY_PCT` | Buzzer duty cycle (%) | `50` | `0..50` (typical `50`) |
| 35 | `CONFIG_STARTUP_BEEP_ON_MS` | Startup beep ON time (ms) | `50` | `10..500` (typical `50`) |
| 36 | `CONFIG_STARTUP_BEEP_GAP_MS` | Startup beep gap time (ms) | `50` | `10..500` (typical `50`) |
| 37 | `CONFIG_STARTUP_BEEP_ENABLE` | Enable startup beeps | `1` | `0/1` |
| 38 | `CONFIG_MP3_VOLUME` | MP3 volume | `25` | `0..30` (typical `25`) |
| 39 | `CONFIG_MP3_ARM_SUCCESS_ENABLE` | Arm-success announcement enable | `1` | `0/1` |
| 40 | `CONFIG_MP3_DEFUSE_SUCCESS_ENABLE` | Defuse-success announcement enable | `1` | `0/1` |
| 41 | `CONFIG_MP3_TRACK_ARM_SUCCESS` | Arm-success track number | `101` | `1..999` (typical `101`) |
| 42 | `CONFIG_MP3_TRACK_EXPLOSION` | Explosion track number | `102` | `1..999` (typical `102`) |
| 43 | `CONFIG_MP3_TRACK_DEFUSE_SUCCESS` | Defuse-success track number | `103` | `1..999` (typical `103`) |
| 44 | `CONFIG_MP3_TRACK_CTWIN` | CT-win track number | `104` | `1..999` (typical `104`) |
| 45 | `CONFIG_MP3_TRACK_TERWIN` | T-win track number | `105` | `1..999` (typical `105`) |
| 46 | `CONFIG_MP3_DEFUSE_STAGE_ENABLE` | MP3 master switch in defuse-success stage | `1` | `0/1` |
| 47 | `CONFIG_MP3_EXPLODED_STAGE_ENABLE` | MP3 master switch in explosion stage | `1` | `0/1` |
| 48 | `CONFIG_MP3_EXPLOSION_ENABLE` | Explosion sound effect enable | `1` | `0/1` |
| 49 | `CONFIG_MP3_CT_WIN_MUSICBOX_ENABLE` | CT music-box enable | `1` | `0/1` |
| 50 | `CONFIG_MP3_T_WIN_MUSICBOX_ENABLE` | T music-box enable | `1` | `0/1` |
| 51 | `CONFIG_MP3_CTWIN_ENABLE` | CT-win announcement enable | `1` | `0/1` |
| 52 | `CONFIG_MP3_TERWIN_ENABLE` | T-win announcement enable | `1` | `0/1` |
| 53 | `CONFIG_MP3_CT_WIN_MUSICBOX_TRACK` | CT music-box track number | `10` | `0..999` (typical `10`) |
| 54 | `CONFIG_MP3_T_WIN_MUSICBOX_TRACK` | T music-box track number | `1` | `0..999` (typical `1`) |
| 55 | `CONFIG_MP3_DEFUSE_SUCCESS_WAIT_MS` | Wait after defuse announcement (ms) | `2700` | `0..20000` (typical `2700`) |
| 56 | `CONFIG_MP3_CT_MUSICBOX_WAIT_MS` | Wait after CT music-box (ms) | `9000` | `0..20000` (typical `9000`) |
| 57 | `CONFIG_MP3_T_MUSICBOX_WAIT_MS` | Wait after T music-box (ms) | `10000` | `0..20000` (typical `10000`) |
| 58 | `CONFIG_MP3_EXPLOSION_ONLY_WAIT_MS` | Wait after explosion-only sound (ms) | `7000` | `0..20000` (typical `7000`) |
| 59 | `CONFIG_EXPLOSION_BEEP_MS` | Pre-explosion beep duration (ms) | `500` | `0..5000` (typical `500`) |
| 60 | `CONFIG_ARM_ERROR_HINT_ENABLE` | Show `ERROR` when preset arm password is wrong | `0` | `0=silent clear, 1=show ERROR then clear` |

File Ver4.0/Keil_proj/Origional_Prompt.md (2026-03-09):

主控STM32F103C8T6，使用keil5+stlink仿真器
外部8MHz高速晶振

A CSGO game C4 bomb model based on stm32

1. 采用LCD1601A来代替原先的LCD1602A。为了还原外观，LCD1601A在板子上是倒置的，所以不能直接用原来从左往右和普通的字符。必须从右往左，并且所有字符都得旋转180度。比如说我想要用户能看到显示左对齐的ABCDEF，那么实际我需要显示的就是右对齐的FEDCBA，并且每个字符都得要自身旋转180度。
这里你可能需要一个完整的倒置的字符表，其实只需要用到这些数字的字符（倒置版）"0123456789*"好像就够了
LCD1601A需要采用4线模式
关于LCD1601A的引脚是这些
#define LCD_RS_PORT GPIOB
#define LCD_RS_PIN GPIO_Pin_12
#define LCD_EN_PORT GPIOB
#define LCD_EN_PIN GPIO_Pin_14

#define LCD_D4_PORT GPIOA
#define LCD_D4_PIN GPIO_Pin_4
#define LCD_D5_PORT GPIOA
#define LCD_D5_PIN GPIO_Pin_5
#define LCD_D6_PORT GPIOA
#define LCD_D6_PIN GPIO_Pin_6
#define LCD_D7_PORT GPIOA
#define LCD_D7_PIN GPIO_Pin_7
LCD1601A采用5V电平，外部我接了上拉到5V的上拉电阻，所以信号脚需要用开漏输出

#define LCD_BLED_PORT GPIOA
#define LCD_BLED_PIN GPIO_Pin_3 (LCD背光板LED，高电平点亮，推挽)

参考代码：#include "1601a.h"
#include "stm32f10x_rcc.h"
#include "delay.h"

static void LCD_SetDataNibble(uint8_t data)
{
	if (data & 0x01) { GPIO_SetBits(LCD_D4_PORT, LCD_D4_PIN); } else { GPIO_ResetBits(LCD_D4_PORT, LCD_D4_PIN); }
	if (data & 0x02) { GPIO_SetBits(LCD_D5_PORT, LCD_D5_PIN); } else { GPIO_ResetBits(LCD_D5_PORT, LCD_D5_PIN); }
	if (data & 0x04) { GPIO_SetBits(LCD_D6_PORT, LCD_D6_PIN); } else { GPIO_ResetBits(LCD_D6_PORT, LCD_D6_PIN); }
	if (data & 0x08) { GPIO_SetBits(LCD_D7_PORT, LCD_D7_PIN); } else { GPIO_ResetBits(LCD_D7_PORT, LCD_D7_PIN); }
}

static void LCD_PulseEnable(void)
{
	GPIO_SetBits(LCD_EN_PORT, LCD_EN_PIN);
	Delay_us(1);
	GPIO_ResetBits(LCD_EN_PORT, LCD_EN_PIN);
	Delay_us(50);
}

static void LCD_Write4Bits(uint8_t nibble)
{
	LCD_SetDataNibble(nibble & 0x0F);
	LCD_PulseEnable();
}

static void LCD_Write8Bits(uint8_t value)
{
	LCD_Write4Bits(value >> 4);
	LCD_Write4Bits(value & 0x0F);
}

void GPIO_INIT(void)
{
	GPIO_InitTypeDef gpio;

	RCC_APB2PeriphClockCmd(RCC_APB2Periph_GPIOA, ENABLE);
	RCC_APB2PeriphClockCmd(RCC_APB2Periph_GPIOB, ENABLE);

	gpio.GPIO_Pin = LCD_RS_PIN | LCD_EN_PIN;
	gpio.GPIO_Mode = GPIO_Mode_Out_OD;
	gpio.GPIO_Speed = GPIO_Speed_50MHz;
	GPIO_Init(GPIOB, &gpio);

	gpio.GPIO_Pin = LCD_DATA_PORTA_PINS;
	gpio.GPIO_Mode = GPIO_Mode_Out_OD;
	gpio.GPIO_Speed = GPIO_Speed_50MHz;
	GPIO_Init(GPIOA, &gpio);

	gpio.GPIO_Pin = GPIO_Pin_3;
	gpio.GPIO_Mode = GPIO_Mode_Out_PP;
	gpio.GPIO_Speed = GPIO_Speed_50MHz;
	GPIO_Init(GPIOA, &gpio);
	GPIO_SetBits(GPIOA, GPIO_Pin_3);
}

void LCD_INIT(void)
{
	GPIO_INIT();

	GPIO_ResetBits(LCD_RS_PORT, LCD_RS_PIN);
	GPIO_ResetBits(LCD_EN_PORT, LCD_EN_PIN);

	Delay_ms(20);
	LCD_Write4Bits(0x03);
	Delay_ms(5);
	LCD_Write4Bits(0x03);
	Delay_ms(5);
	LCD_Write4Bits(0x03);
	Delay_ms(1);
	LCD_Write4Bits(0x02);

	LCD_WRITE_CMD(0x28);
	LCD_WRITE_CMD(0x08);
	LCD_WRITE_CMD(0x01);
	Delay_ms(2);
	LCD_WRITE_CMD(0x06);
	LCD_WRITE_CMD(0x0C);
}

void LCD_WRITE_CMD(unsigned char CMD)
{
	GPIO_ResetBits(LCD_RS_PORT, LCD_RS_PIN);
	LCD_Write8Bits(CMD);
	if (CMD == 0x01 || CMD == 0x02)
	{
		Delay_ms(2);
	}
	else
	{
		Delay_us(50);
	}
}

void LCD_WRITE_ByteDATA(unsigned char ByteData)
{
	GPIO_SetBits(LCD_RS_PORT, LCD_RS_PIN);
	LCD_Write8Bits(ByteData);
	Delay_us(50);
}

void LCD_SetCursor(unsigned char Column)
{
	if (Column <= 7)
	{
		LCD_WRITE_CMD(0x80 | Column);
	}
	else
	{
		LCD_WRITE_CMD(0x80 | (Column - 8) + 0x40);
	}
}

void LCD_WRITE_StrDATA(unsigned char *StrData, unsigned char col)
{
	unsigned char i;

	for (i = 0; StrData[i] != '\0'; i++)
	{
		LCD_SetCursor(col);
		LCD_WRITE_ByteDATA(StrData[i]);
		col++;
	}
}

void WUserImg(unsigned char pos, unsigned char *ImgInfo)
{
	unsigned char cgramAddr;

	if (pos <= 1) cgramAddr = 0x40;
	if (pos > 1 && pos <= 3) cgramAddr = 0x50;
	if (pos > 3 && pos <= 5) cgramAddr = 0x60;
	if (pos > 5 && pos <= 7) cgramAddr = 0x70;

	LCD_WRITE_CMD((cgramAddr + (pos % 2) * 8));

	while (*ImgInfo != '\0')
	{
		LCD_WRITE_ByteDATA(*ImgInfo);
		ImgInfo++;
	}
}

2. 矩阵键盘
PB15 PB4 PB5 PB6 PB7 PB8 PB9
排列为：
        PB5     PB15    PB7
PB4     [1]     [2]     [3]
PB9     [4]     [5]     [6]
PB8     [7]     [8]     [9]
PB6     [*]     [0]     [#]

3. 蜂鸣器
无源蜂鸣器（已包含驱动电路，mos管，栅极10k下拉，栅极连接PB0）
PB0发出PWM波驱动

4. LED
PC13-系统指示LED（一般不用，调试才用）（推挽高电平点亮）

用户指示双色LED（推挽高电平点亮）
PA2-红
PA1-绿
如果需要黄色就要红绿同时点亮PA2和PA1，并且需要PWM调节（比如黄色100%的时候，红色大约是70%，绿色100%，因为人眼对红色感度比绿色高。输出黄色50，红色35%，绿色50%）

5. 继电器（已包含mos+续流驱动电路）
PB1高电平-继电器吸合

6. MP3模块。
PA9串口通讯，用来播放C4模型的音乐盒或者音效
参考代码：
#include "stm32f10x.h"                  // Device header
#include <stdio.h>
#include <stdarg.h>

/**
  * 函    数：串口初始化
  * 参    数：无
  * 返 回 值：无
  */
void Serial_Init(void)
{
	/*开启时钟*/
	RCC_APB2PeriphClockCmd(RCC_APB2Periph_USART1, ENABLE);	//开启USART1的时钟
	RCC_APB2PeriphClockCmd(RCC_APB2Periph_GPIOA, ENABLE);	//开启GPIOA的时钟
	
	/*GPIO初始化*/
	GPIO_InitTypeDef GPIO_InitStructure;
	GPIO_InitStructure.GPIO_Mode = GPIO_Mode_AF_PP;
	GPIO_InitStructure.GPIO_Pin = GPIO_Pin_9;
	GPIO_InitStructure.GPIO_Speed = GPIO_Speed_50MHz;
	GPIO_Init(GPIOA, &GPIO_InitStructure);					//将PA9引脚初始化为复用推挽输出
	
	/*USART初始化*/
	USART_InitTypeDef USART_InitStructure;					//定义结构体变量
	USART_InitStructure.USART_BaudRate = 9600;				//波特率
	USART_InitStructure.USART_HardwareFlowControl = USART_HardwareFlowControl_None;	//硬件流控制，不需要
	USART_InitStructure.USART_Mode = USART_Mode_Tx;			//模式，选择为发送模式
	USART_InitStructure.USART_Parity = USART_Parity_No;		//奇偶校验，不需要
	USART_InitStructure.USART_StopBits = USART_StopBits_1;	//停止位，选择1位
	USART_InitStructure.USART_WordLength = USART_WordLength_8b;		//字长，选择8位
	USART_Init(USART1, &USART_InitStructure);				//将结构体变量交给USART_Init，配置USART1
	
	/*USART使能*/
	USART_Cmd(USART1, ENABLE);								//使能USART1，串口开始运行
}

/**
  * 函    数：串口发送一个字节
  * 参    数：Byte 要发送的一个字节
  * 返 回 值：无
  */
void Serial_SendByte(uint8_t Byte)
{
	USART_SendData(USART1, Byte);		//将字节数据写入数据寄存器，写入后USART自动生成时序波形
	while (USART_GetFlagStatus(USART1, USART_FLAG_TXE) == RESET);	//等待发送完成
	/*下次写入数据寄存器会自动清除发送完成标志位，故此循环后，无需清除标志位*/
}

/**
  * 函    数：串口发送一个数组
  * 参    数：Array 要发送数组的首地址
  * 参    数：Length 要发送数组的长度
  * 返 回 值：无
  */
void Serial_SendArray(uint8_t *Array, uint16_t Length)
{
	uint16_t i;
	for (i = 0; i < Length; i ++)		//遍历数组
	{
		Serial_SendByte(Array[i]);		//依次调用Serial_SendByte发送每个字节数据
	}
}

/**
  * 函    数：串口发送一个字符串
  * 参    数：String 要发送字符串的首地址
  * 返 回 值：无
  */
void Serial_SendString(char *String)
{
	uint8_t i;
	for (i = 0; String[i] != '\0'; i ++)//遍历字符数组（字符串），遇到字符串结束标志位后停止
	{
		Serial_SendByte(String[i]);		//依次调用Serial_SendByte发送每个字节数据
	}
}

/**
  * 函    数：次方函数（内部使用）
  * 返 回 值：返回值等于X的Y次方
  */
uint32_t Serial_Pow(uint32_t X, uint32_t Y)
{
	uint32_t Result = 1;	//设置结果初值为1
	while (Y --)			//执行Y次
	{
		Result *= X;		//将X累乘到结果
	}
	return Result;
}

/**
  * 函    数：串口发送数字
  * 参    数：Number 要发送的数字，范围：0~4294967295
  * 参    数：Length 要发送数字的长度，范围：0~10
  * 返 回 值：无
  */
void Serial_SendNumber(uint32_t Number, uint8_t Length)
{
	uint8_t i;
	for (i = 0; i < Length; i ++)		//根据数字长度遍历数字的每一位
	{
		Serial_SendByte(Number / Serial_Pow(10, Length - i - 1) % 10 + '0');	//依次调用Serial_SendByte发送每位数字
	}
}

/**
  * 函    数：使用printf需要重定向的底层函数
  * 参    数：保持原始格式即可，无需变动
  * 返 回 值：保持原始格式即可，无需变动
  */
int fputc(int ch, FILE *f)
{
	Serial_SendByte(ch);			//将printf的底层重定向到自己的发送字节函数
	return ch;
}

/**
  * 函    数：自己封装的prinf函数
  * 参    数：format 格式化字符串
  * 参    数：... 可变的参数列表
  * 返 回 值：无
  */
void Serial_Printf(char *format, ...)
{
	char String[100];				//定义字符数组
	va_list arg;					//定义可变参数列表数据类型的变量arg
	va_start(arg, format);			//从format开始，接收参数列表到arg变量
	vsprintf(String, format, arg);	//使用vsprintf打印格式化字符串和参数列表到字符数组中
	va_end(arg);					//结束变量arg
	Serial_SendString(String);		//串口发送字符数组（字符串）
}

#include "stm32f10x.h"
#include "Serial.h"
#include "delay.h"

/*
音乐序号  音乐名
			0	  虚空
			1	  军团
			2	  新黑色电影
			3	  困兽
			4	  神枪手
			5   追溯起源
			6   竞技场
			7		冲破藩篱
			8		咄咄逼人
			9		哥特浮华
			10	大胆尝试
			11	GLA
			12		漂泊者
			13		战火星空
			14	黄色魔法
			15	巨龙之眼
			16	咖啡拉花
			17	巴克拉姆
			18	电锯追命
			19	决心
			20	燥起来
			21	尘归尘
			22	A.D.8
			23	疤王
			24	万夫莫敌包
			25	终极
			26	大局入侵
			27	同型节奏
			28	地球末夜
			29	莫洛托夫烈火
			30	无人之境
			31	理由
			32	精彩时刻
			33	超爆话筒
			34	叛乱
			35	雄狮之口
			36	沙漠之焰
			37	好好干，好好活
			38	深红突击
			39	骷髅爆破
			40	绝对统御
			41	金属
			42	如日中天
			43	永恒之钻
			44	圣诞之歌
			45	你急了
			46	蜂鸟
			47	海绵手指
			48	8位音乐盒
			49	迈阿密热线
			50	令人发指
			51	躺平青年
			52	爆头
			53	闪光舞
			54	尖峰时刻
			55	塔罗斯的法则
			56	有害物质环境
			57	就是我
			58	EZ4ENCE
			59	爪哇哈瓦那放克乐
			60	触摸能量
			61	通宵达旦
			62	非人类
			63	花脸
			64	征服
			65	万众瞩目
			66	冲击星
			67	人生何处不青山
			68	枪炮卷饼卡车
			69	有为青年
			70	光环：士官长合集
			71	黑帝斯音乐盒
			72	反叛者
			73	Ben Bromfield,Rabbit Hole
			74	Daniel Sadowski,Dead Shot
			75	Sam Marshall,Clutch
			76	Tree Adams,Seventh Moon
			77	Tim Huling,Devil's Paintbrush
			78	Dren McDonald,Coffee!Kofe Kahveh!
			79	Matt Levine,Agency
			80	Austin Wintory,The Devil Went Clubbing in Georgia
			81	诶嘿

			82 c4上电下包
			83 c4下包完成
			84 c4倒计时结束爆炸_完整

*/
#include "stm32f10x.h"
#include "Serial.h"

uint8_t Send_buf[10];
void MP3CMD(uint8_t CMD , uint16_t data)
{

    Send_buf[0] = 0x7e;    //头
    Send_buf[1] = 0xff;    //保留字节 
    Send_buf[2] = 0x06;    //长度
    Send_buf[3] = CMD;     //控制指令
    Send_buf[4] = 0x00;    //是否需要反馈
	Send_buf[5] = (uint8_t)(data >> 8);    //data
    Send_buf[6] = (uint8_t)(data);   //data
	Send_buf[7] = ((~(0xff+0x06+CMD+data))+1) >> 8;    //校验和
	Send_buf[8] = ((~(0xff+0x06+CMD+data))+1)&0x00ff;//校验和
    Send_buf[9] = 0xef;    //尾
	
	for (u8 i = 0; i < 10; i ++)		//遍历数组
	{
		Serial_SendByte(Send_buf[i]);	  //依次调用Serial_SendByte发送每个字节数据
	}

}

void mp3_Init(void)
{
	Serial_Init();
}

void mp3_start(void)//上电提示音
{
	MP3CMD(0x12,100);
}

void mp3_over(void)//下包结束音
{
	MP3CMD(0x12,101);  
}

void mp3_boom(void)//c4爆炸音
{
	MP3CMD(0x12,102);
}

void mp3_boom_music(void)//默认播放02文件夹内000xxx.MP3歌曲
{
	
//	MP3CMD(0x0f,0x0251);
	
	Send_buf[0] = 0x7e;    //头
    Send_buf[1] = 0xff;    //保留字节 
    Send_buf[2] = 0x06;    //长度
    Send_buf[3] = 0x0f;     //控制指令
    Send_buf[4] = 0x00;    //是否需要反馈
	Send_buf[5] = 0x02;    //data
    Send_buf[6] = 0x00;
	Send_buf[7] = 0xfe;
	Send_buf[8] = 0xea;
    Send_buf[9] = 0xef;    //尾
	
	for (u8 i = 0; i < 10; i ++)		//遍历数组
	{
		Serial_SendByte(Send_buf[i]);	  //依次调用Serial_SendByte发送每个字节数据
	}

}

7. 外部“拆弹器”
PB3上拉输入，如果下拉就进入“拆弹器拆弹模式”，拆弹时间只需要5秒，也就是PB3连续外部下拉5秒，就算拆弹成功

流程：

LED先是黄色呼吸灯模式，周期500ms
上电后先快速哔哔两声以4250Hz。

倒计时的时候蜂鸣器为3600Hz
然后等待输入密码，密码7位数，输入7位数后先不要直接立马进入倒计时模式，而是多等待一会防止用户最后一位数输错了。然后记录此密码（输入密码的时候LED依然是呼吸灯模式）
然后进入倒计时模式，倒计时按照原版的时间和pattern来。每次beep的时候LED亮红色，不beep的时候LED熄灭
In short, here is the formula for the beep pattern of the CS:GO bomb:

f(t) = 1.05 · exp(0.0054t + 0.000871t²)

Where f(t) gives the BPS (Beeps Per Second), and t (0 ≤ t ≤ 45) is the time in seconds (the in-game bomb explodes after 45 seconds).

For a more generalized formula:

g(p) = 1.049 · exp(0.244p + 1.764p²)

Where g(p) gives the BPS (Beeps Per Second), and p (0.0 ≤ p ≤ 1.0) is the percentage of the time that has passed since the bomb has been armed. This is more useful when you don’t want to be stuck using the 45 second explosion time frame.

The length of each beep is fixed at 125ms per beep. These formulas approximate the beep pattern of CS:GO’s bomb very accurately.

If anyone has ever wondered what the formula for the bomb beeping interval is..

Thanks to the code leak

freq = MAX( 0.1 + 0.9 * fComplete, 0.15 );

where fComplete is the percentage of the time that's left (40/40 when planted and 0/40 at the end)

When the bomb is planted, it sets the time for the next beep to gpGlobals->curtime + 1.0...

倒计时的时候LCD1601A显示滚动的“*”号。原来的实现是这样：void TIM2_IRQHandler(void)//中断函数，每秒执行20次
{
	if (TIM_GetITStatus(TIM2, TIM_IT_Update) == SET)
	{
		if(Num_sign == 0)
		{
			Num ++;											
			TIM_ClearITPendingBit(TIM2, TIM_IT_Update);	
			if(Num>=13){Num_sign=1;}
		}
		else
		{
			Num --;											
			TIM_ClearITPendingBit(TIM2, TIM_IT_Update);
			if(Num<=0){Num_sign=0;}
		}
	}
}
void lcdupdate(void)
{
	static int dt=0;
	static char lcdtp=0;
	dt++;
	if(dt>=30000)
	{
		switch(lcdtp)
		{
			case 0:
				LCD_WRITE_StrDATA("*            ",0);
				lcdtp++;
				break;
			case 1:
				LCD_WRITE_StrDATA(" *           ",0);
				lcdtp++;
				break;
			case 2:
				LCD_WRITE_StrDATA("  *          ",0);
				lcdtp++;
				break;
			case 3:
				LCD_WRITE_StrDATA("   *         ",0);
				lcdtp++;
				break;
			default:
				LCD_WRITE_StrDATA("    *        ",0);
				lcdtp=0;
				break;
		}
		dt=0;
	}
}
要注意，现在LCD1601A是反装的，所以符号啊，位置啊都要翻转180度

倒计时过程中拆弹有3种情况：（并且都要非阻塞，比如就算拆弹失败或者拆弹过程中，倒计时的时间什么的都不能变，之前老版本的因为扫描键盘和倒计时循环都是阻塞的导致如果长按某个按键，会因为按键消抖延时的问题导致倒计时的循环时间不准确）
1. 直接输入密码，直接按键盘输入和下包一样的密码，则为拆弹成功
2. 长按#进入破解手动拆弹模式，耗时10秒必能成功拆除，拆弹的动画是每一位数字从0123456789跳变10次，然后定格在正确的那位数，然后再是下一位跳变，然后定格，下一位，每次只“爆破”一位数，直到完整的密码显现出来。
3. 拆弹器拆弹，动画和手动爆破拆弹一样，但是速度快一倍，只需5秒就能拆包。
注意，输入密码的数字出现顺序和拆弹的数字输入左右顺序不一样，可以参考原先的代码你就懂了。
拆弹成功会播放拆弹成功效果

如果倒计时结束而没有拆弹，那么继电器吸合，然后播放音效和音乐盒，同时LED输出100%黄色（LED和播放音乐盒同时）。

参考老版代码。
现在这个工程有一些是早期版本（例如无 MP3 且使用 1602 的方案）以及后续多个版本代码的混合，所以你大概需要全部重写一下了。

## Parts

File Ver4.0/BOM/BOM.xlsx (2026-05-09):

器件 | 位号 | 数量 | 图片仅供参考，请按照文字器件描述购买 | 备注
STM32F103C8T6-LQFP48 | U5 | 1
LCD1601a(黄绿色)（不焊排针）5V | LCD1 | 1 |  | 不要买错成1602。不要买焊接好排针的版本
单片机矩阵键盘3*4 |  | 1 |  | 这家店的外观和字体最像
钮子开关 开关+大红盖 |  | 1 |  | 注意方向，向上拨是ON，向下是OFF
9V电池 |  | 1 |  | 推荐南孚9V碱性电池。碳性电池可能带不动
9V电池扣I型硬扣 |  | 1
无源蜂鸣器4kHz 5V | BUZ1 | 1 |  | 或者 2-7V，或者包含5V的就行
LED5mm 红绿双色 共阴极3脚 | LED1 | 1
HK-4100F-DC5V汇科继电器 | K1 | 1
排针2.54mm 1*9P 针长17~23mm均可 |  | 1 |  | 建议针长19~23mm，17mm我试了有点短了
电缆0.5平方纯铜（红黑黄） |  | 1
KF2510连接线 |  | 1 |  | 电源线
22pF | C1,C4 | 2 |  | 贴片电容，封装为0805 C0805
100nF | C5,C6,C7,C8,C9 | 5 |  | C0805
10uF | C10,C11 | 2 |  | C0805
33uH | L1 | 1 |  | 1040电感
LED_0805-G | LED2 | 1 |  | 绿色LED贴片0805
LED_0805-R | LED3 | 1 |  | 红色LED贴片0805
240 | R6 /LCD-R1 | 2 |  | 贴片电阻240欧姆0805封装/ 注LCD转接板背面的R1需要焊接此电阻
68 | R5 | 1 |  | 68欧姆-0805
1K | R1,R2 | 2 |  | 1k-0805 / 这里的R1指的是主板上的R1，转接板上的R1请焊接240R
10K | R3,R7,R8,R9,R10,R11,R12,R13,R14,R15,R16,R17 | 12 |  | 10k-0805
Key_SMD_3x4x2 | REBOOM/RST1 | 1 |  | KEY-SMD_2P-L6.2-W3.6-LS8.0
LM2596S-5.0(UMW) | U1 | 1 |  | TO-263-5_L10.2-W8.9-P1.70-BR
AO3400 | U6,U10,U13 | 3 |  | SOT-23-3_L2.9-W1.3-P1.90-LS2.4-BL-2
AMS1117-3.3V | U7 | 1 |  | SOT_223
1N5819/SOD-123 | U8,U11 | 2 |  | SOD-123_L2.7-W1.7-LS3.8-RD
KF103-5.0-2P | U9,U12 | 2 |  | CONN-TH_P5.00_KF103-5.0-2P
8MHZ | X1 | 1 |  | HC-49S_L11.5-W5.0-P4.88_1
FC-10P 2mm间距 100mm长度 |  | 1
FC-10P 2mm间距 200mm长度 |  | 1
电解电容16V 2200uF直插10*20mm | U2,U3,U4 | 3
固态电解电容1000uF 16V 10*12mm | C2,C3 | 2
KF2510母座2P直针 | CN1,CN2 | 2
IDC2.0-2*5PZ | CN3,CN4,CN5,LCD转接板 | 4
SS14 | D1 | 1 |  | SMA_L4.3-W2.6-LS5.2-RD
2.54*8P排针母座 | H4,H3 | 2 |  | 用来链接MP3模块
2.54*9P排针母座 | H5 | 1 |  | 连接键盘用
3362电位器10k欧姆 | R4 | 1
mini mp3 player模块 |  | 1 |  | 建议买这家
8Ω1W或8Ω2W喇叭（直径<30mm） | SPK1,SPK2 | 1 |  | 焊接时不用分正负极
TF卡 |  | 1 |  | 容量最便宜的128MB就够了
银灰色PVC警示胶带 30mm宽度 |  | 1
黑色电工胶布
ST-link V2
A4牛皮纸浅色 |  |  |  | 浅色，A4
3D打印填充物以及开关外壳 |  |  |  | 可选，自己用纸板做一个也一样
各类焊接工具：电烙铁、焊锡丝、镊子、热熔胶/胶枪等等
一双勤劳的双手
一个敏捷的头脑
一份坚持的内心

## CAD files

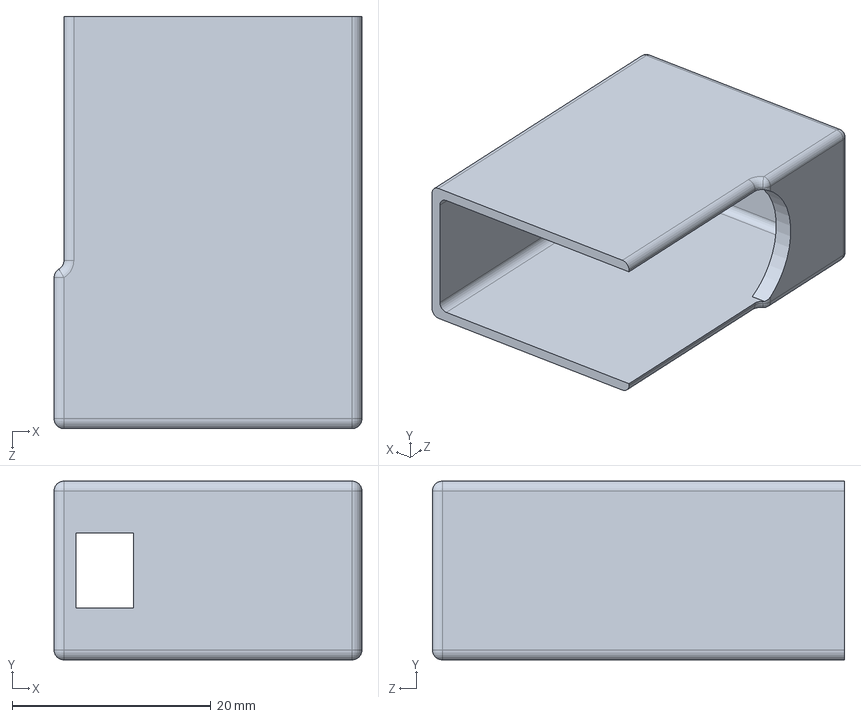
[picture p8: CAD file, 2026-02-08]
Ver4.0/3DP_Models/switch_shell.SLDPRT
31.0 x 18.0 x 41.5 mm

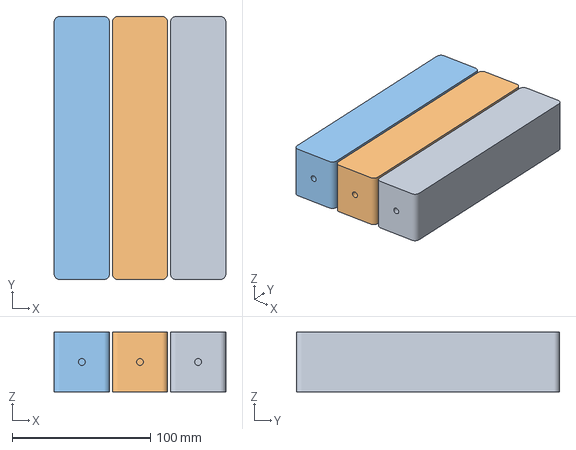
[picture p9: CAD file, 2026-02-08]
Ver4.0/3DP_Models/C4_filler.3mf
124.0 x 190.0 x 43.0 mm
c4填充物.STL x 3

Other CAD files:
Ver4.0/3DP_Models/C4_filler.STL
Ver4.0/3DP_Models/switch_shell.STL

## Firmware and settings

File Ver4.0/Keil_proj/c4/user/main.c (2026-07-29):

#include "stm32f10x.h"
#include "MatrixKey.h"
#include "1601a.h"
#include "Delay.h"
#include "LED.h"
#include "Systick.h"
#include "mp3.h"
#include "config.h"
#include "config_manager.h"
#include <math.h>
#include <string.h>

typedef enum
{
	STATE_IDLE = 0,
	STATE_COUNTDOWN,
	STATE_DEFUSE_SUCCESS,
	STATE_EXPLODED
} AppState;

typedef enum
{
	DEFUSE_NONE = 0,
	DEFUSE_MANUAL,
	DEFUSE_EXTERNAL
} DefuseMode;

typedef struct
{
	uint8_t active;
	DefuseMode mode;
	uint32_t step_ms;
	uint32_t next_step_ms;
	uint8_t digit_index;
	uint8_t cycle_step;
	uint32_t flash_step;
	char display[CONFIG_PASSWORD_LEN_MAX + 1U];
} DefuseAnim;

typedef enum
{
	MP3_SEQ_NONE = 0,
	MP3_SEQ_DEFUSE,
	MP3_SEQ_EXPLOSION
} Mp3Sequence;

typedef enum
{
	CFG_MODE_IDLE = 0,
	CFG_MODE_INPUT_ID,
	CFG_MODE_CONFIRM_RESTORE,
	CFG_MODE_INPUT_VALUE,
	CFG_MODE_CONFIRM_SAVE
} ConfigModeState;

static AppState app_state = STATE_IDLE;
static DefuseMode defuse_mode = DEFUSE_NONE;

static char arm_input[CONFIG_PASSWORD_LEN_MAX + 1U];
static char arm_code[CONFIG_PASSWORD_LEN_MAX + 1U];
static char defuse_input[CONFIG_PASSWORD_LEN_MAX + 1U];
static uint8_t defuse_pos = 0;

static uint32_t arm_last_change_ms = 0;
static uint32_t countdown_end_ms = 0;
static uint32_t next_beep_ms = 0;
static uint32_t beep_off_ms = 0;
static uint8_t beep_active = 0;

static uint32_t scroll_next_ms = 0;
static uint16_t scroll_pos = 0;
static uint8_t scroll_dir = 0;
static unsigned char scroll_line[CONFIG_LCD_COLS_MAX + 1U];

static uint32_t last_defuse_input_ms = 0;
static uint32_t hash_hold_ms = 0;
static uint8_t config_boot_latched = 0;
static uint8_t config_hold_armed = 0;

static char success_pluses[CONFIG_PASSWORD_LEN_MAX + 1U];
static char success_minuses[CONFIG_PASSWORD_LEN_MAX + 1U];
static uint8_t success_frame = 0;
static uint32_t success_next_ms = 0;

static uint8_t startup_beep_state = 0;
static uint32_t startup_beep_next_ms = 0;
static uint8_t success_beep_state = 0;
static uint32_t success_beep_next_ms = 0;
static uint8_t explosion_stage = 0;
static uint32_t explosion_stage_next_ms = 0;

static DefuseAnim defuse_anim;
static Mp3Sequence mp3_seq = MP3_SEQ_NONE;
static uint8_t mp3_seq_step = 0;
static uint32_t mp3_seq_next_ms = 0;

static ConfigModeState cfg_mode_state = CFG_MODE_IDLE;
static AppConfig cfg_edit;
static char cfg_input[17];
static uint8_t cfg_input_len = 0;
static uint16_t cfg_selected_id = 0;

uint8_t g_password_len = CONFIG_PASSWORD_LEN;
uint8_t g_lcd_cols = CONFIG_LCD_COLS;
uint8_t g_lcd_normal_mount = CONFIG_LCD_NORMAL_MOUNT;
uint8_t g_password_col = CONFIG_PASSWORD_COL;
uint32_t g_countdown_ms = CONFIG_COUNTDOWN_MS;
uint32_t g_arm_delay_ms = CONFIG_ARM_DELAY_MS;
uint8_t g_arm_preset_enable = CONFIG_ARM_PRESET_ENABLE;
char g_arm_preset_password[CONFIG_PASSWORD_LEN_MAX + 1U] = CONFIG_ARM_PRESET_PASSWORD;
uint8_t g_arm_error_hint_enable = CONFIG_ARM_ERROR_HINT_ENABLE;

uint8_t g_defuse_enable_password = CONFIG_DEFUSE_ENABLE_PASSWORD;
uint8_t g_defuse_enable_manual = CONFIG_DEFUSE_ENABLE_MANUAL;
uint8_t g_defuse_enable_external = CONFIG_DEFUSE_ENABLE_EXTERNAL;

uint8_t g_lcd_backlight_pct = CONFIG_LCD_BACKLIGHT_PCT;

uint32_t g_beep_len_ms = CONFIG_BEEP_LEN_MS;
uint32_t g_beep_interval_base_ms = CONFIG_BEEP_INTERVAL_BASE_MS;
uint32_t g_beep_interval_scale_ms = CONFIG_BEEP_INTERVAL_SCALE_MS;
uint32_t g_beep_interval_min_ms = CONFIG_BEEP_INTERVAL_MIN_MS;
uint32_t g_beep_initial_ms = CONFIG_BEEP_INITIAL_MS;

uint16_t g_led_pwm_max = CONFIG_LED_PWM_MAX;
uint32_t g_led_breath_period_ms = CONFIG_LED_BREATH_PERIOD_MS;
uint8_t g_led_yellow_red_pct = CONFIG_LED_YELLOW_RED_PCT;

uint32_t g_scroll_interval_ms = CONFIG_SCROLL_INTERVAL_MS;
uint8_t g_scroll_pattern_len = CONFIG_SCROLL_PATTERN_LEN;
uint8_t g_digital_countdown_enable = CONFIG_DIGITAL_COUNTDOWN_ENABLE;

uint32_t g_long_press_ms = CONFIG_LONG_PRESS_MS;
uint32_t g_manual_defuse_ms = CONFIG_MANUAL_DEFUSE_MS;
uint32_t g_external_defuse_ms = CONFIG_EXTERNAL_DEFUSE_MS;
uint32_t g_defuse_display_hold_ms = CONFIG_DEFUSE_DISPLAY_HOLD_MS;
uint8_t g_defuse_cycle_steps = CONFIG_DEFUSE_CYCLE_STEPS;

uint32_t g_defuse_flash_toggle_ms = CONFIG_DEFUSE_FLASH_TOGGLE_MS;
uint8_t g_defuse_flash_toggles = CONFIG_DEFUSE_FLASH_TOGGLES;
uint32_t g_defuse_blink_ms = CONFIG_DEFUSE_BLINK_MS;

uint32_t g_buzzer_startup_freq_hz = CONFIG_BUZZER_STARTUP_FREQ_HZ;
uint32_t g_buzzer_countdown_freq_hz = CONFIG_BUZZER_COUNTDOWN_FREQ_HZ;
uint8_t g_buzzer_duty_pct = CONFIG_BUZZER_DUTY_PCT;
uint32_t g_startup_beep_on_ms = CONFIG_STARTUP_BEEP_ON_MS;
uint32_t g_startup_beep_gap_ms = CONFIG_STARTUP_BEEP_GAP_MS;
uint8_t g_startup_beep_enable = CONFIG_STARTUP_BEEP_ENABLE;

uint8_t g_mp3_volume = CONFIG_MP3_VOLUME;
uint8_t g_mp3_arm_success_enable = CONFIG_MP3_ARM_SUCCESS_ENABLE;
uint8_t g_mp3_defuse_success_enable = CONFIG_MP3_DEFUSE_SUCCESS_ENABLE;

uint16_t g_mp3_track_arm_success = CONFIG_MP3_TRACK_ARM_SUCCESS;
uint16_t g_mp3_track_explosion = CONFIG_MP3_TRACK_EXPLOSION;
uint16_t g_mp3_track_defuse_success = CONFIG_MP3_TRACK_DEFUSE_SUCCESS;
uint16_t g_mp3_track_ctwin = CONFIG_MP3_TRACK_CTWIN;
uint16_t g_mp3_track_terwin = CONFIG_MP3_TRACK_TERWIN;

uint8_t g_mp3_defuse_stage_enable = CONFIG_MP3_DEFUSE_STAGE_ENABLE;
uint8_t g_mp3_exploded_stage_enable = CONFIG_MP3_EXPLODED_STAGE_ENABLE;

uint8_t g_mp3_explosion_enable = CONFIG_MP3_EXPLOSION_ENABLE;
uint8_t g_mp3_ct_win_musicbox_enable = CONFIG_MP3_CT_WIN_MUSICBOX_ENABLE;
uint8_t g_mp3_t_win_musicbox_enable = CONFIG_MP3_T_WIN_MUSICBOX_ENABLE;
uint8_t g_mp3_ctwin_enable = CONFIG_MP3_CTWIN_ENABLE;
uint8_t g_mp3_terwin_enable = CONFIG_MP3_TERWIN_ENABLE;

uint16_t g_mp3_ct_win_musicbox_track = CONFIG_MP3_CT_WIN_MUSICBOX_TRACK;
uint16_t g_mp3_t_win_musicbox_track = CONFIG_MP3_T_WIN_MUSICBOX_TRACK;

uint32_t g_mp3_defuse_success_wait_ms = CONFIG_MP3_DEFUSE_SUCCESS_WAIT_MS;
uint32_t g_mp3_ct_musicbox_wait_ms = CONFIG_MP3_CT_MUSICBOX_WAIT_MS;
uint32_t g_mp3_t_musicbox_wait_ms = CONFIG_MP3_T_MUSICBOX_WAIT_MS;
uint32_t g_mp3_explosion_only_wait_ms = CONFIG_MP3_EXPLOSION_ONLY_WAIT_MS;
uint32_t g_explosion_beep_ms = CONFIG_EXPLOSION_BEEP_MS;

#define MP3_CT_MUSICBOX_BASE 1000U
#define MP3_T_MUSICBOX_BASE 2000U
#define EXPLOSION_BEEP_FREQ_HZ 3600U

static void Runtime_Apply(const AppConfig *cfg)
{
	if (cfg == 0)
	{
		return;
	}

	g_password_len = (uint8_t)cfg->password_len;
	g_lcd_cols = (uint8_t)cfg->lcd_cols;
	g_lcd_normal_mount = (uint8_t)cfg->lcd_normal_mount;
	g_password_col = (uint8_t)cfg->password_col;
	g_countdown_ms = cfg->countdown_ms;
	g_arm_delay_ms = cfg->arm_delay_ms;
	g_arm_preset_enable = (uint8_t)cfg->arm_preset_enable;
	strncpy(g_arm_preset_password, cfg->arm_preset_password, CONFIG_PASSWORD_LEN_MAX);
	g_arm_preset_password[CONFIG_PASSWORD_LEN_MAX] = '\0';
	g_arm_error_hint_enable = (uint8_t)cfg->arm_error_hint_enable;

	g_defuse_enable_password = (uint8_t)cfg->defuse_enable_password;
	g_defuse_enable_manual = (uint8_t)cfg->defuse_enable_manual;
	g_defuse_enable_external = (uint8_t)cfg->defuse_enable_external;

	g_lcd_backlight_pct = (uint8_t)cfg->lcd_backlight_pct;

	g_beep_len_ms = cfg->beep_len_ms;
	g_beep_interval_base_ms = cfg->beep_interval_base_ms;
	g_beep_interval_scale_ms = cfg->beep_interval_scale_ms;
	g_beep_interval_min_ms = cfg->beep_interval_min_ms;
	g_beep_initial_ms = cfg->beep_initial_ms;

	g_led_pwm_max = (uint16_t)cfg->led_pwm_max;
	g_led_breath_period_ms = cfg->led_breath_period_ms;
	g_led_yellow_red_pct = (uint8_t)cfg->led_yellow_red_pct;

	g_scroll_interval_ms = cfg->scroll_interval_ms;
	g_scroll_pattern_len = (uint8_t)cfg->scroll_pattern_len;
	g_digital_countdown_enable = (uint8_t)cfg->digital_countdown_enable;

	g_long_press_ms = cfg->long_press_ms;
	g_manual_defuse_ms = cfg->manual_defuse_ms;
	g_external_defuse_ms = cfg->external_defuse_ms;
	g_defuse_display_hold_ms = cfg->defuse_display_hold_ms;
	g_defuse_cycle_steps = (uint8_t)cfg->defuse_cycle_steps;

	g_defuse_flash_toggle_ms = cfg->defuse_flash_toggle_ms;
	g_defuse_flash_toggles = (uint8_t)cfg->defuse_flash_toggles;
	g_defuse_blink_ms = cfg->defuse_blink_ms;

	g_buzzer_startup_freq_hz = cfg->buzzer_startup_freq_hz;
	g_buzzer_countdown_freq_hz = cfg->buzzer_countdown_freq_hz;
	g_buzzer_duty_pct = (uint8_t)cfg->buzzer_duty_pct;
	g_startup_beep_on_ms = cfg->startup_beep_on_ms;
	g_startup_beep_gap_ms = cfg->startup_beep_gap_ms;
	g_startup_beep_enable = (uint8_t)cfg->startup_beep_enable;

	g_mp3_volume = (uint8_t)cfg->mp3_volume;
	g_mp3_arm_success_enable = (uint8_t)cfg->mp3_arm_success_enable;
	g_mp3_defuse_success_enable = (uint8_t)cfg->mp3_defuse_success_enable;

	g_mp3_track_arm_success = (uint16_t)cfg->mp3_track_arm_success;
	g_mp3_track_explosion = (uint16_t)cfg->mp3_track_explosion;
	g_mp3_track_defuse_success = (uint16_t)cfg->mp3_track_defuse_success;
	g_mp3_track_ctwin = (uint16_t)cfg->mp3_track_ctwin;
	g_mp3_track_terwin = (uint16_t)cfg->mp3_track_terwin;

	g_mp3_defuse_stage_enable = (uint8_t)cfg->mp3_defuse_stage_enable;
	g_mp3_exploded_stage_enable = (uint8_t)cfg->mp3_exploded_stage_enable;

	g_mp3_explosion_enable = (uint8_t)cfg->mp3_explosion_enable;
	g_mp3_ct_win_musicbox_enable = (uint8_t)cfg->mp3_ct_win_musicbox_enable;
	g_mp3_t_win_musicbox_enable = (uint8_t)cfg->mp3_t_win_musicbox_enable;
	g_mp3_ctwin_enable = (uint8_t)cfg->mp3_ctwin_enable;
	g_mp3_terwin_enable = (uint8_t)cfg->mp3_terwin_enable;

	g_mp3_ct_win_musicbox_track = (uint16_t)cfg->mp3_ct_win_musicbox_track;
	g_mp3_t_win_musicbox_track = (uint16_t)cfg->mp3_t_win_musicbox_track;

	g_mp3_defuse_success_wait_ms = cfg->mp3_defuse_success_wait_ms;
	g_mp3_ct_musicbox_wait_ms = cfg->mp3_ct_musicbox_wait_ms;
	g_mp3_t_musicbox_wait_ms = cfg->mp3_t_musicbox_wait_ms;
	g_mp3_explosion_only_wait_ms = cfg->mp3_explosion_only_wait_ms;
	g_explosion_beep_ms = cfg->explosion_beep_ms;
}

static void DefuserInput_Init(void)
{
	GPIO_InitTypeDef gpio;

	RCC_APB2PeriphClockCmd(RCC_APB2Periph_GPIOB | RCC_APB2Periph_AFIO, ENABLE);
	GPIO_PinRemapConfig(GPIO_Remap_SWJ_JTAGDisable, ENABLE);

	gpio.GPIO_Pin = GPIO_Pin_3;
	gpio.GPIO_Mode = GPIO_Mode_IPU;
	gpio.GPIO_Speed = GPIO_Speed_50MHz;
	GPIO_Init(GPIOB, &gpio);
}

static uint8_t Defuser_IsActive(void)
{
	return (GPIO_ReadInputDataBit(GPIOB, GPIO_Pin_3) == 0) ? 1U : 0U;
}

static void Password_Fill(char *buf, char fill)
{
	uint8_t i;
	for (i = 0; i < g_password_len; i++)
	{
		buf[i] = fill;
	}
	buf[g_password_len] = '\0';
}

static void Password_Reset(char *buf)
{
	Password_Fill(buf, '+');
}

static uint8_t Password_HasDigit(const char *buf)
{
	uint8_t i;
	for (i = 0; i < g_password_len; i++)
	{
		if (buf[i] >= '0' && buf[i] <= '9')
		{
			return 1U;
		}
	}
	return 0U;
}

static uint8_t Password_IsComplete(const char *buf)
{
	return (buf[0] >= '0' && buf[0] <= '9') ? 1U : 0U;
}

static void Password_InputRight(char *buf, char key)
{
	uint8_t i;
	if (key >= '0' && key <= '9')
	{
		if (!Password_HasDigit(buf))
		{
			Password_Fill(buf, '-');
		}
		for (i = 0; i < g_password_len - 1U; i++)
		{
			buf[i] = buf[i + 1U];
		}
		buf[g_password_len - 1U] = key;
	}
	else if (key == '*')
	{
		for (i = g_password_len - 1U; i > 0U; i--)
		{
			buf[i] = buf[i - 1U];
		}
		buf[0] = '-';
		if (!Password_HasDigit(buf))
		{
			Password_Reset(buf);
		}
	}
	else if (key == '#')
	{
		Password_Reset(buf);
	}
}

static void Password_InputLeft(char *buf, uint8_t *pos, char key)
{
	if (key >= '0' && key <= '9')
	{
		if (*pos < g_password_len)
		{
			buf[*pos] = key;
			(*pos)++;
		}
	}
	else if (key == '*')
	{
		if (*pos > 0U)
		{
			(*pos)--;
			buf[*pos] = '+';
		}
	}
	else if (key == '#')
	{
		Password_Reset(buf);
		*pos = 0U;
	}
}

static uint8_t Password_Match(const char *a, const char *b)
{
	return (memcmp(a, b, g_password_len) == 0) ? 1U : 0U;
}

static void LCD_ClearLine(void)
{
	static unsigned char spaces[] = "                ";
	LCD_BeginFrame();
	LCD_WRITE_StrDATA(spaces, 0);
}

static void LCD_WriteFixed(const char *text, uint8_t col, uint8_t width)
{
	unsigned char out[17];
	uint8_t i;
	for (i = 0; i < width && i < 16U; i++)
	{
		char ch = text[i];
		if (ch == '\0')
		{
			break;
		}
		out[i] = (unsigned char)ch;
	}
	for (; i < width && i < 16U; i++)
	{
		out[i] = ' ';
	}
	out[(width > 16U) ? 16U : width] = '\0';
	LCD_WRITE_StrDATA(out, col);
}

static void LCD_ShowPassword(const char *buf)
{
	LCD_BeginFrame();
	LCD_ClearLine();
	LCD_WRITE_StrDATA_Password((unsigned char *)buf, g_password_col, g_password_len);
}

static uint16_t LCD_ScrollMaxPos(void)
{
	if (g_digital_countdown_enable)
	{
		return (uint16_t)((g_lcd_cols - 1U) / 2U);
	}
	return (uint16_t)(g_lcd_cols - 1U);
}

static void LCD_ShowScrollWithTime(uint16_t pos, uint32_t now)
{
	uint16_t max_pos = LCD_ScrollMaxPos();
	uint16_t i;
	uint32_t remain_ms;
	uint32_t remain_sec;
	uint32_t mm;
	uint32_t ss;
	unsigned char right[9];

	if (pos > max_pos)
	{
		pos = max_pos;
	}

	LCD_BeginFrame();

	for (i = 0; i < g_lcd_cols; i++)
	{
		scroll_line[i] = ' ';
	}
	scroll_line[g_lcd_cols] = '\0';

	if (pos > 0U)
	{
		scroll_line[pos - 1U] = '+';
	}
	scroll_line[pos] = '+';
	if (pos < max_pos)
	{
		scroll_line[pos + 1U] = '+';
	}

	if (g_digital_countdown_enable && defuse_mode == DEFUSE_NONE)
	{
		if (now >= countdown_end_ms)
		{
			remain_ms = 0U;
		}
		else
		{
			remain_ms = countdown_end_ms - now;
		}
		remain_sec = remain_ms / 1000U;
		mm = remain_sec / 60U;
		ss = remain_sec % 60U;

		right[0] = ' ';
		right[1] = ' ';
		right[2] = (unsigned char)('0' + ((mm / 10U) % 10U));
		right[3] = (unsigned char)('0' + (mm % 10U));
		right[4] = ':';
		right[5] = (unsigned char)('0' + ((ss / 10U) % 10U));
		right[6] = (unsigned char)('0' + (ss % 10U));
		right[7] = ' ';
		right[8] = '\0';

		for (i = 0; i < 8U && i < g_lcd_cols; i++)
		{
			scroll_line[g_lcd_cols - 8U + i] = right[i];
		}
	}

	LCD_WRITE_StrDATA(scroll_line, 0);
}

static void LED_Breath(uint32_t now)
{
	uint32_t half = g_led_breath_period_ms / 2U;
	uint32_t phase = (g_led_breath_period_ms == 0U) ? 0U : (now % g_led_breath_period_ms);
	uint16_t level;
	uint16_t max_pwm = LED_GetPwmMax();

	if (half == 0U)
	{
		half = 1U;
	}

	if (phase < half)
	{
		level = (uint16_t)((phase * max_pwm) / half);
	}
	else
	{
		level = (uint16_t)(((g_led_breath_period_ms - phase) * max_pwm) / half);
	}
	LED_SetYellow(level);
}

static void StartupBeep_Update(uint32_t now)
{
	if (startup_beep_state >= 4U)
	{
		return;
	}
	if (now < startup_beep_next_ms)
	{
		return;
	}
	switch (startup_beep_state)
	{
		case 0:
			Buzzer_On();
			startup_beep_next_ms = now + g_startup_beep_on_ms;
			startup_beep_state = 1;
			break;
		case 1:
			Buzzer_Off();
			startup_beep_next_ms = now + g_startup_beep_gap_ms;
			startup_beep_state = 2;
			break;
		case 2:
			Buzzer_On();
			startup_beep_next_ms = now + g_startup_beep_on_ms;
			startup_beep_state = 3;
			break;
		case 3:
			Buzzer_Off();
			startup_beep_state = 4;
			break;
		default:
			break;
	}
}

static void SuccessBeep_Start(uint32_t now)
{
	success_beep_state = 0U;
	success_beep_next_ms = now;
	Buzzer_SetFreq(g_buzzer_startup_freq_hz);
}

static void SuccessBeep_Update(uint32_t now)
{
	if (success_beep_state >= 6U)
	{
		return;
	}
	if (now < success_beep_next_ms)
	{
		return;
	}
	switch (success_beep_state)
	{
		case 0:
			Buzzer_On();
			success_beep_next_ms = now + g_startup_beep_on_ms;
			success_beep_state = 1;
			break;
		case 1:
			Buzzer_Off();
			success_beep_next_ms = now + g_startup_beep_gap_ms;
			success_beep_state = 2;
			break;
		case 2:
			Buzzer_On();
			success_beep_next_ms = now + g_startup_beep_on_ms;
			success_beep_state = 3;
			break;
		case 3:
			Buzzer_Off();
			success_beep_next_ms = now + g_startup_beep_gap_ms;
			success_beep_state = 4;
			break;
		case 4:
			Buzzer_On();
			success_beep_next_ms = now + g_startup_beep_on_ms;
			success_beep_state = 5;
			break;
		case 5:
			Buzzer_Off();
			success_beep_state = 6;
			break;
		default:
			break;
	}
}

static void MP3Sequence_Stop(void)
{
	mp3_seq = MP3_SEQ_NONE;
	mp3_seq_step = 0U;
	mp3_seq_next_ms = 0U;
}

static uint16_t MP3_TrackCtMusicbox(uint16_t track)
{
	return (uint16_t)(MP3_CT_MUSICBOX_BASE + track);
}

static uint16_t MP3_TrackTMusicbox(uint16_t track)
{
	return (uint16_t)(MP3_T_MUSICBOX_BASE + track);
}
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
int main(void)
{
	uint32_t now;
	uint32_t init_now;
	uint32_t config_hold_start_ms;
	uint32_t config_boot_latch_deadline_ms;
	char key;
	char hold;
	uint8_t defuser_active;

	Timebase_Init();
	DefuserInput_Init();
	ConfigManager_Init();
	Runtime_Apply(ConfigManager_Get());

	LED_Init();
	Buzzer_Init();
	Buzzer_SetFreq(g_buzzer_startup_freq_hz);
	Buzzer_SetDuty(g_buzzer_duty_pct);
	LCD_INIT();
	MatrixKey_Init();
	mp3_Init();
	Delay_ms(200);
	mp3_SetVolume(g_mp3_volume);

	init_now = Timebase_Millis();
	startup_beep_next_ms = init_now;
	startup_beep_state = g_startup_beep_enable ? 0U : 4U;

	Password_Reset(arm_input);
	Password_Reset(arm_code);
	Password_Reset(defuse_input);
	LCD_ShowPassword(arm_input);
	config_hold_start_ms = 0U;
	config_boot_latched = 0U;
	config_hold_armed = 0U;
	config_boot_latch_deadline_ms = init_now + 120U;

	while (1)
	{
		now = Timebase_Millis();
		MatrixKey_Update();
		key = MatrixKey_GetValue();
		hold = MatrixKey_GetHold();
		defuser_active = Defuser_IsActive();

		if (!config_boot_latched)
		{
			if (hold == '#')
			{
				config_boot_latched = 1U;
				config_hold_armed = 1U;
				config_hold_start_ms = now;
			}
			else if (hold != ' ')
			{
				config_boot_latched = 1U;
				config_hold_armed = 0U;
			}
			else if (now >= config_boot_latch_deadline_ms)
			{
				config_boot_latched = 1U;
				config_hold_armed = 0U;
			}
		}

		if (app_state == STATE_IDLE && config_hold_armed)
		{
			if (hold == '#')
			{
				if ((now - config_hold_start_ms) >= 300U)
				{
					Buzzer_Off();
					ConfigMode_Init();
					while (1)
					{
						uint32_t cfg_now = Timebase_Millis();
						StartupBeep_Update(cfg_now);
						LED_Breath(cfg_now);
						MatrixKey_Update();
						key = MatrixKey_GetValue();
						if (ConfigMode_Update(key))
						{
							while (1)
							{
								uint32_t wait_now = Timebase_Millis();
								StartupBeep_Update(wait_now);
								LED_Breath(wait_now);
							}
						}
					}
				}
			}
			else
			{
				config_hold_armed = 0U;
				config_hold_start_ms = 0U;
			}
		}

		StartupBeep_Update(now);
		MP3Sequence_Update(now);

		switch (app_state)
		{
			case STATE_IDLE:
				LED_Breath(now);
				if (key != ' ')
				{
					Password_InputRight(arm_input, key);
					LCD_ShowPassword(arm_input);
					arm_last_change_ms = now;
				}
				if (Password_IsComplete(arm_input) && (now - arm_last_change_ms) >= g_arm_delay_ms)
				{
					if (g_arm_preset_enable)
					{
						if (Password_Match(arm_input, g_arm_preset_password))
						{
							memcpy(arm_code, g_arm_preset_password, g_password_len + 1U);
							Countdown_Start(now);
						}
						else
						{
							if (g_arm_error_hint_enable)
							{
								LCD_BeginFrame();
								LCD_ClearLine();
								LCD_WriteFixed("ERROR", 0, 16);
							}
							Password_Reset(arm_input);
							if (!g_arm_error_hint_enable)
							{
								LCD_ShowPassword(arm_input);
							}
							arm_last_change_ms = now;
						}
					}
					else
					{
						memcpy(arm_code, arm_input, g_password_len + 1U);
						Countdown_Start(now);
					}
				}
				break;
			case STATE_COUNTDOWN:
				if (g_defuse_enable_manual)
				{
					if (defuse_mode == DEFUSE_NONE && hold == '#')
					{
						if (hash_hold_ms == 0U)
						{
							hash_hold_ms = now;
						}
						else if ((now - hash_hold_ms) >= g_long_press_ms)
						{
							DefuseAnim_Start(now, DEFUSE_MANUAL);
							hash_hold_ms = 0U;
						}
					}
					else
					{
						hash_hold_ms = 0U;
					}
				}
				else
				{
					hash_hold_ms = 0U;
				}

				if (g_defuse_enable_external)
				{
					if (defuse_mode == DEFUSE_NONE && defuser_active)
					{
						DefuseAnim_Start(now, DEFUSE_EXTERNAL);
					}
				}

				if (DefuseAnim_Update(now, defuser_active, hold))
				{
					Defuse_Success(now);
					break;
				}

				if (g_defuse_enable_password && defuse_mode == DEFUSE_NONE)
				{
					if (key != ' ')
					{
						Password_InputLeft(defuse_input, &defuse_pos, key);
						LCD_ShowPassword(defuse_input);
						last_defuse_input_ms = now;
					}

					if (defuse_pos >= g_password_len)
					{
						if (Password_Match(arm_code, defuse_input))
						{
							Defuse_Success(now);
							break;
						}
						Password_Reset(defuse_input);
						defuse_pos = 0U;
						LCD_ShowPassword(defuse_input);
					}
					if (defuse_pos == 0U && (now - last_defuse_input_ms) > g_defuse_display_hold_ms)
					{
						Countdown_UpdateScroll(now);
					}
				}
				else if (defuse_mode == DEFUSE_NONE)
				{
					if ((now - last_defuse_input_ms) > g_defuse_display_hold_ms)
					{
						Countdown_UpdateScroll(now);
					}
				}

				Countdown_UpdateBeep(now);
				if (beep_active)
				{
					LED_SetColor(LED_GetPwmMax(), 0U);
				}
				else
				{
					LED_AllOff();
				}

				if (now >= countdown_end_ms)
				{
					Explosion_Start(now);
				}
				break;
			case STATE_DEFUSE_SUCCESS:
				LED_SetGreen(LED_GetPwmMax());
				SuccessBeep_Update(now);
				if (now >= success_next_ms)
				{
					success_frame = (uint8_t)((success_frame + 1U) % 3U);
					success_next_ms = now + g_defuse_blink_ms;
					if (success_frame == 0U)
					{
						LCD_ShowPassword(success_pluses);
					}
					else if (success_frame == 1U)
					{
						LCD_ShowPassword(success_minuses);
					}
					else
					{
						LCD_ShowPassword(arm_code);
					}
				}
				break;
			case STATE_EXPLODED:
				LED_SetYellow(LED_GetPwmMax());
				if (explosion_stage == 1U)
				{
					if (now >= explosion_stage_next_ms)
					{
						Buzzer_Off();
						explosion_stage = 2U;
						explosion_stage_next_ms = now;
					}
				}
				if (explosion_stage == 2U)
				{
					Relay_On();
					MP3Sequence_StartExplosion(now);
					explosion_stage = 3U;
				}
				break;
			default:
				LED_Breath(now);
				break;
		}
	}
}

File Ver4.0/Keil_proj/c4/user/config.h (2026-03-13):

#ifndef CONFIG_H
#define CONFIG_H

/*
 * Single source of default configuration.
 * - Edit values in this file.
 * - Reflash to apply firmware defaults.
 */

#define CONFIG_IGNORE_RANGE 0U

#define CONFIG_PASSWORD_LEN 7U
#define CONFIG_LCD_COLS 16U
#define CONFIG_LCD_NORMAL_MOUNT 0U
#define CONFIG_PASSWORD_COL 3U
#define CONFIG_COUNTDOWN_MS 40000U
#define CONFIG_ARM_DELAY_MS 800U

#define CONFIG_ARM_PRESET_ENABLE 0U
#define CONFIG_ARM_PRESET_PASSWORD "1234567"
#define CONFIG_ARM_ERROR_HINT_ENABLE 0U

#define CONFIG_DEFUSE_ENABLE_PASSWORD 1U
#define CONFIG_DEFUSE_ENABLE_MANUAL 1U
#define CONFIG_DEFUSE_ENABLE_EXTERNAL 1U

#define CONFIG_LCD_BACKLIGHT_PCT 50U

#define CONFIG_BEEP_LEN_MS 125U
#define CONFIG_BEEP_INTERVAL_BASE_MS 100U
#define CONFIG_BEEP_INTERVAL_SCALE_MS 900U
#define CONFIG_BEEP_INTERVAL_MIN_MS 150U
#define CONFIG_BEEP_INITIAL_MS 1000U

#define CONFIG_LED_PWM_MAX 1000U
#define CONFIG_LED_BREATH_PERIOD_MS 700U
#define CONFIG_LED_YELLOW_RED_PCT 40U

#define CONFIG_SCROLL_INTERVAL_MS 50U
#define CONFIG_SCROLL_PATTERN_LEN 3U
#define CONFIG_DIGITAL_COUNTDOWN_ENABLE 0U

#define CONFIG_LONG_PRESS_MS 200U
#define CONFIG_MANUAL_DEFUSE_MS 10000U
#define CONFIG_EXTERNAL_DEFUSE_MS 5000U
#define CONFIG_DEFUSE_DISPLAY_HOLD_MS 1200U
#define CONFIG_DEFUSE_CYCLE_STEPS 10U

#define CONFIG_DEFUSE_FLASH_TOGGLE_MS 10U
#define CONFIG_DEFUSE_FLASH_TOGGLES 8U
#define CONFIG_DEFUSE_BLINK_MS 400U

#define CONFIG_BUZZER_STARTUP_FREQ_HZ 4250U
#define CONFIG_BUZZER_COUNTDOWN_FREQ_HZ 3600U
#define CONFIG_BUZZER_DUTY_PCT 50U
#define CONFIG_STARTUP_BEEP_ON_MS 50U
#define CONFIG_STARTUP_BEEP_GAP_MS 50U
#define CONFIG_STARTUP_BEEP_ENABLE 1U

#define CONFIG_MP3_VOLUME 25U
#define CONFIG_MP3_ARM_SUCCESS_ENABLE 1U
#define CONFIG_MP3_DEFUSE_SUCCESS_ENABLE 1U

#define CONFIG_MP3_TRACK_ARM_SUCCESS 101U
#define CONFIG_MP3_TRACK_EXPLOSION 102U
#define CONFIG_MP3_TRACK_DEFUSE_SUCCESS 103U
#define CONFIG_MP3_TRACK_CTWIN 104U
#define CONFIG_MP3_TRACK_TERWIN 105U

#define CONFIG_MP3_DEFUSE_STAGE_ENABLE 1U
#define CONFIG_MP3_EXPLODED_STAGE_ENABLE 1U

#define CONFIG_MP3_EXPLOSION_ENABLE 1U
#define CONFIG_MP3_CT_WIN_MUSICBOX_ENABLE 1U
#define CONFIG_MP3_T_WIN_MUSICBOX_ENABLE 1U
#define CONFIG_MP3_CTWIN_ENABLE 1U
#define CONFIG_MP3_TERWIN_ENABLE 1U

#define CONFIG_MP3_CT_WIN_MUSICBOX_TRACK 10U
#define CONFIG_MP3_T_WIN_MUSICBOX_TRACK 1U

#define CONFIG_MP3_DEFUSE_SUCCESS_WAIT_MS 2700U
#define CONFIG_MP3_CT_MUSICBOX_WAIT_MS 9000U
#define CONFIG_MP3_T_MUSICBOX_WAIT_MS 10000U
#define CONFIG_MP3_EXPLOSION_ONLY_WAIT_MS 7000U

#define CONFIG_EXPLOSION_BEEP_MS 500U

#define CONFIG_RESET_MAGIC 90405U
#define CONFIG_RESET_CODE "090405"

#include "config_range.h"

#endif

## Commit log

2026-01-23 Add new version V4.0
    [硬件清单C4.xlsx]
2026-03-08 update bom
    [BOM.xlsx]
2026-03-09 Fully removed V1 version supply
    [硬件清单C4.xlsx]
2026-07-12 修正 LCD1601 适配器图片格式为 JPG
2026-07-29 还原 CS2 显示动画并完善忽略规则

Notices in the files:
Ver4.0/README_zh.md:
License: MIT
